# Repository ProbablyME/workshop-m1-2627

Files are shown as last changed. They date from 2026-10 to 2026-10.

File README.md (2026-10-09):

# Sentinel-X — Avant-poste industriel autonome (Groupe 1)

Prototype cyber-physique réalisé pour le Workshop EPSI M1 2026-27 « Mission Sentinel-X »
(AetherCorp Industrial Solutions). Un boîtier ESP8266 équipé de capteurs environnementaux
et de présence remonte ses données en MQTT chiffré vers un **PC Serveur Local** (option B :
laptop d'un apprenant) qui héberge la stack Docker, l'API, le dashboard de supervision et
l'IA de vision sur webcam USB.

## Architecture (option B)

```
                 Wi-Fi (sous-réseau de table 192.168.10.0/24)
                 (cible ; en démo, repli possible sur un hotspot partagé : seul MQTT_HOST change dans secrets.h)
┌────────────────────┐   MQTTS 8883 (TLS)   ┌──────────────────────────────────────────┐
│  Boîtier SENTINEL-X│ ───────────────────► │  PC Serveur Local (laptop)               │
│  ESP8266 NodeMCU   │ ◄─────────────────── │  ┌────────────┐  ┌──────┐  ┌──────────┐  │
│  DHT22 · MQ-2 · PIR│   sentinel/g1/cmd    │  │ Mosquitto  │─►│ API  │─►│ Postgres │  │
│  OLED · Buzzer · LED│                     │  └────────────┘  │FastAPI│ └──────────┘  │
└────────────────────┘                      │        ▲         └──┬───┘               │
                                            │        │            │ WebSocket + REST   │
                      Webcam USB ──────────►│  ┌─────┴─────┐  ┌───▼──────────────┐     │
                                            │  │ IA vision │  │ Dashboard React  │     │
                                            │  │ + prédictif│  │ (supervision)    │     │
                                            │  └───────────┘  └──────────────────┘     │
                                            └──────────────────────────────────────────┘
```

Détails : [docs/ARCHITECTURE.md](docs/ARCHITECTURE.md). Interfaces entre blocs :
[docs/CONTRAT_DONNEES.md](docs/CONTRAT_DONNEES.md) (référence unique pour les 4 filières).
Montage électronique : [docs/CABLAGE.md](docs/CABLAGE.md). Boîtier et Fablab : [docs/BOITIER.md](docs/BOITIER.md).
Base de données (schéma, console SQL, requêtes) : [docs/BASE_DE_DONNEES.md](docs/BASE_DE_DONNEES.md).

## Structure du dépôt

| Dossier | Filière | Contenu | État |
|---|---|---|---|
| `firmware/`  | DEV | Firmware ESP8266 C++ (PlatformIO / CLion) : capteurs, OLED, MQTTS, commandes | **fait** |
| `backend/` | DEV | API FastAPI : MQTT ↔ PostgreSQL ↔ WebSocket, `POST /api/v1/alerts` | **fait** |
| `dashboard/` | DEV | Interface React (tuiles, courbes temps réel, alertes, commandes, IA) | **fait** |
| `ai/` | IA | Vision YOLOv8n (intrusion + flux vidéo) et maintenance prédictive Isolation Forest | **fait** |
| `infra/` | INFRA | Config Mosquitto (TLS), scripts certificats / mots de passe / bootstrap | **fait** |
| `docs/` | tous | Contrat de données, architecture, câblage, boîtier, matrice de sécurité, rapport d'audit | en cours |
| `fablab/` | tous | Plaque de gravure laser (SVG), exports Fusion360 à venir | en cours |

## Démarrage rapide (PC Serveur Local)

Prérequis : Docker Desktop (ou Docker Engine + Compose v2), OpenSSL, Python 3.12+.

```bash
# 1. Génère .env (secrets aléatoires), la CA + le certificat MQTTS, le fichier de mots de passe
./infra/scripts/bootstrap.sh 192.168.10.1        # ← IP du laptop sur le réseau de table

# 2. Construit et lance Mosquitto + PostgreSQL + API
docker compose up -d --build

# 3. Vérifie
curl http://localhost:8000/api/v1/health
# → {"status":"ok","mqtt_connected":true,"db_ok":true,"ws_clients":0,"version":"0.1.0"}
```

Documentation interactive de l'API : http://localhost:8000/docs
Dashboard de supervision : http://localhost:8080 (utilisateur et mot de passe `DASHBOARD_*` du `.env`).

Si le port 8000 est déjà pris sur la machine, définir `API_PORT=8010` (ou autre) dans `.env`.

## Tester sans le boîtier physique

Un simulateur publie de la télémétrie et des alertes réalistes sur le broker :

```bash
python3 -m venv backend/.venv && backend/.venv/bin/pip install -r backend/requirements.txt
backend/.venv/bin/python backend/tools/simulate_esp.py --period 2 --intrusion      # MQTT 1883
backend/.venv/bin/python backend/tools/simulate_esp.py --tls --drift               # MQTTS 8883, dérive lente temp+gaz
```

Puis :

```bash
curl http://localhost:8000/api/v1/telemetry/latest
curl -X POST http://localhost:8000/api/v1/commands \
     -H "X-API-Key: $API_KEY" -H 'Content-Type: application/json' \
     -d '{"actuator":"buzzer","action":"pulse","duration_ms":1500}'
```

## Lancer l'IA (hors Docker, sur le laptop serveur)

```bash
cd ai && /opt/homebrew/bin/python3.12 -m venv .venv && .venv/bin/pip install -r requirements.txt
.venv/bin/python vision.py          # webcam → YOLOv8n, alerte intrusion, flux http://localhost:8001/stream
.venv/bin/python predict.py         # Isolation Forest sur la télémétrie, score toutes les 30 s
```

Détails dans [ai/README.md](ai/README.md).

## Développer le dashboard (hors Docker)

```bash
cd dashboard
npm install
npm run dev          # http://localhost:5173, proxifie /api et /ws vers l'API du .env (API_PORT)
npm run build        # build de production dans dist/, servi par nginx dans Docker
```

Le serveur Vite et nginx injectent tous deux l'en-tête `X-API-Key` côté serveur : la clé
n'apparaît jamais dans le code livré au navigateur. `?theme=dark` ou `?theme=light` dans l'URL
force le thème (utile pour l'écran du jury).

## Lancer l'API hors Docker (dev)

```bash
cd backend
DATABASE_URL=sqlite:///./sentinel-dev.db MQTT_HOST=localhost API_KEY=dev \
  .venv/bin/uvicorn app.main:app --reload --port 8000
```

Sans broker joignable, l'API démarre quand même (health en `degraded`) et les routes HTTP
restent utilisables, ce qui suffit pour développer le dashboard.

## Endpoints principaux

| Méthode | Route | Rôle |
|---|---|---|
| GET | `/api/v1/health` | état API / broker / base |
| POST | `/api/v1/alerts` | **endpoint obligatoire du sujet** |
| GET | `/api/v1/alerts` | historique des alertes |
| GET | `/api/v1/telemetry/latest` | dernière mesure |
| GET | `/api/v1/telemetry?minutes=30`  | série temporelle |
| POST | `/api/v1/commands` | pilote buzzer / LED via MQTT |
| GET | `/api/v1/devices` | état du boîtier (online, IP, firmware) |
| POST | `/api/v1/ai/detections` | détections de la vision IA |
| POST | `/api/v1/ai/predictions` | scores d'anomalie du modèle prédictif |
| WS | `/ws` | flux temps réel pour le dashboard |

Les écritures exigent l'en-tête `X-API-Key` (valeur `API_KEY` du `.env`).

## Sécurité

- **Aucun secret dans le dépôt** : `.env`, `infra/mosquitto/passwd`, `infra/mosquitto/certs/`
  et `firmware/include/secrets.h` sont ignorés par Git. Les secrets sont générés par `bootstrap.sh`.
- **MQTTS** : listener 8883 avec CA locale ; l'ESP8266 vérifie le serveur (CA ou empreinte SHA-1
  affichée par `gen-certs.sh`). Authentification login/mot de passe obligatoire (`allow_anonymous false`).
- Le listener 1883 en clair ne sert qu'au debug sur la table ; le fermer (UFW) avant le pentest.
- PostgreSQL n'expose aucun port sur l'hôte. L'API tourne sans privilège root dans son conteneur.
- Limites Mosquitto (`max_connections`, `max_queued_messages`, `max_packet_size`) contre le flood.
- Mosquitto avertit que `passwd` est lisible par tous (`644`) : nécessaire pour que le conteneur
  (uid 1883) le lise via le bind mount ; le fichier est hors Git.
- Hardening de l'hôte (UFW, SSH par clés, Docker) : voir `docs/` (à compléter jeudi).

## Jour de démo : maintien en condition opérationnelle

- Empêcher la veille du laptop serveur pendant la démo : `caffeinate -dims` dans un terminal, ou
  Réglages Système → Batterie → ne jamais mettre en veille sur secteur. Constaté le 5 octobre :
  98 minutes sans télémétrie pendant une veille du Mac, le boîtier s'est reconnecté seul au réveil.
- Laptop sur secteur, Wi-Fi de table en 2,4 GHz, `docker compose ps` tout en `healthy` avant de passer.
- Surveiller `heap_free` dans la télémétrie : ≈ 17,6 Ko après la session TLS, alerter sous 10 Ko.

## Équipe & conventions

- Groupe 1 — livrables nommés `Workshop2026-M1-G1-*`.
- Membres : Leo PIRONTI, Khalid FILALI, Ethan BREUZARD, Antoine LACHAUX, Lucas MATTERA, Cyprien BROCHE.
- Commits sémantiques : `feat(firmware): …`, `fix(api): …`, `docs: …`, `infra: …`.
- Toute modification d'interface passe d'abord par `docs/CONTRAT_DONNEES.md`.

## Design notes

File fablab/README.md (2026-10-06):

# Fablab : fichiers pour la découpe/gravure laser et l'impression 3D

| Fichier | Machine | Contenu |
|---|---|---|
| `plaque-gravure.svg` | Falcon A1 (laser)  | plaque 80 × 50 mm : logo AetherCorp, SENTINEL-X, S/N, sécurité |
| `boitier.py` → `export/*.step`, `*.stl` | K2 Plus (3D) | boîtier paramétrique généré par CadQuery : base, couvercle, gabarit de face ; STEP à importer dans Fusion 360 pour la finition |

Conventions du SVG : **noir** = gravure, **rouge** (trait 0,1 mm) = découpe. Dans LightBurn,
chaque couleur devient un calque avec ses propres vitesse/puissance. Convertir les textes en
chemins dans Inkscape (Chemin → Objet en chemin) si la police manque sur le poste laser.

Spécifications complètes du boîtier : [docs/BOITIER.md](../docs/BOITIER.md).

## Boîtier 3D : génération et import dans Fusion 360

```bash
cd fablab
/opt/homebrew/bin/python3.12 -m venv .venv && .venv/bin/pip install cadquery   # une fois (≈ 1,4 Go)
.venv/bin/python boitier.py                       # cotes par défaut
.venv/bin/python boitier.py --pack 118 62 --holes 108 52   # pack myDiL mesuré au pied à coulisse
```

Les cotes (parois 1,2 mm, positions des découpes, entraxe du pack, logement de la plaque) sont dans la
section PARAMÈTRES de `boitier.py`. Dans Fusion 360 : *Insérer → Insérer un fichier CAO* sur chaque
`.step` ; les corps sont modifiables (chanfreins, logos, ajustements). Imprimer d'abord
`gabarit-face.stl` (15 min) pour vérifier les découpes sur les vrais composants, puis `base.stl`
(ouverture vers le haut, sans support) et `couvercle.stl` (à plat, logement de la plaque vers le haut).

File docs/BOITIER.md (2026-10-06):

# Boîtier SENTINEL-X : spécifications pour la CAO (Fusion360) et le Fablab

Consignes du sujet : modélisation sur **Fusion360 exclusivement**, impression sur Creality K2 Plus,
cloisons **1,2 mm maximum**, électronique encapsulée proprement, **écran OLED visible**,
passe-câbles propres **sans fil apparent**, plaque gravée au laser (logo AetherCorp, consignes
de sécurité, numéro de série). L'impression 3D est longue : lancer la base dès lundi soir.

## 1. Ce qu'il y a à loger (mesurer au pied à coulisse lundi, valeurs indicatives)

| Élément | Encombrement (L × l × h) | Contrainte de montage |
|---|---|---|
| Pack myDiL (ESP + 2 breadboards) | **à mesurer**, ≈ 115 × 60 × 22 mm | 4 oreilles de fixation : relever l'entraxe des trous, ne pas désassembler |
| OLED 0.96" I2C | PCB 27 × 27 mm, 4 trous Ø2 (entraxe ≈ 23,5 mm) | zone d'affichage 22 × 11 mm décalée vers le haut du PCB |
| PIR HC-SR501 | PCB 32 × 24 mm, dôme Ø 23 mm, h ≈ 25 mm | trou Ø 23,5 mm en face avant, dôme en saillie, potentiomètres accessibles |
| MQ-2 (module) | PCB 32 × 20 mm, capsule Ø 16 mm, h ≈ 22 mm | grille d'aération obligatoire, chauffe (≈ 50 °C) |
| DHT22 (module) | 38 × 20 × 8 mm | fentes d'aération, loin du MQ-2 pour ne pas fausser la température |
| Buzzer actif | Ø 12 mm, h 9 mm | grille de 5 à 7 trous Ø 2 mm devant |
| LED bicolore 5 mm | Ø 5 mm | trou Ø 5,2 mm, collée ou support LED |
| Convertisseur DC-DC | ≈ 43 × 21 × 12 mm | production uniquement |
| 2 Wago + arrivée 7,5 V | ≈ 20 × 13 × 8 mm chacun | passe-câble Ø 6 mm ou presse-étoupe |
| Micro-USB de l'ESP | ouverture 12 × 8 mm | alignée sur le port, accessible sans ouvrir le boîtier |

## 2. Architecture proposée : 3 pièces

Modèle généré par `fablab/boitier.py` (CadQuery → STEP/STL, voir `fablab/README.md`), à importer et finaliser dans Fusion 360.

1. **Base** (le plus long à imprimer, à lancer en premier) : bac avec 4 plots à vis pour le pack
   myDiL, logements DC-DC et Wago, ouverture micro-USB latérale, passe-câble d'alimentation,
   pieds et chanfreins 45° pour imprimer sans support.
2. **Face avant** (pièce fine, rapide) : fenêtre OLED avec 4 plots, trou PIR, trou LED, grille
   buzzer, grille MQ-2, fentes DHT22, et l'emplacement en retrait pour la plaque gravée.
3. **Couvercle** : fermeture par 4 vis M3 (inserts chauffants ou trous Ø 2,8 mm pour vis
   autotaraudeuses), aérations latérales.

Dimensions intérieures cibles : ≈ 140 × 95 × 55 mm. À ajuster après mesure du pack.

## 3. Paramètres Fusion360 (User Parameters, pour tout ajuster en 30 secondes)

| Paramètre | Valeur | Commentaire |
|---|---|---|
| `wall` | 1,2 mm | consigne myDiL, = 3 lignes de buse 0,4 mm |
| `clear` | 0,3 mm | jeu entre pièces imprimées |
| `inner_L` | 140 mm | longueur intérieure |
| `inner_W` | 95 mm  | largeur intérieure |
| `inner_H` | 55 mm  | hauteur intérieure |
| `screw` | 2,8 mm | trou vis M3 autotaraudeuse |
| `pir_hole` | 23,5 mm| dôme PIR |
| `led_hole` | 5,2 mm | LED 5 mm |
| `oled_win_W` | 24 mm  | fenêtre écran (zone active 22 mm + jeu) |
| `oled_win_H` | 13 mm  | |
| `plate_L` | 80 mm  | plaque gravée laser |
| `plate_W` | 50 mm  | |
| `plate_T` | 3 mm | plexi ou bois 3 mm |

## 4. Réglages d'impression (Creality Print / K2 Plus)

- Matière PLA, buse 0,4 mm, couches 0,2 mm, parois 3 lignes (1,2 mm), remplissage 15 % gyroïde.
- Pas de support : toutes les ouvertures latérales en forme de « pont » ≤ 10 mm ou avec chanfrein 45° en haut.
- Orienter la face avant à plat, fenêtre vers le haut. Base ouverture vers le haut.
- Temps estimé : base ≈ 4 à 5 h, face avant ≈ 1 h, couvercle ≈ 2 h. Lancer la base lundi soir.
- Première impression : un **gabarit de test** 2 mm d'épaisseur avec juste les découpes (OLED, PIR, LED) pour vérifier les cotes en 15 minutes avant d'imprimer la vraie face.

## 5. Gravure et découpe laser (Falcon A1)

- Support : plexi 3 mm (rendu « produit fini ») ou contreplaqué 3 mm (plus rapide).
- Fichier : `fablab/plaque-gravure.svg`, 80 × 50 mm. Noir = gravure, rouge = découpe.
- Contenu : logo AetherCorp, « SENTINEL-X · Edge Node », S/N `SX-G1-01`, pictogrammes de sécurité
  (tension 7,5 V, ne pas ouvrir sous tension, surface chaude côté MQ-2), « Groupe 1 · EPSI 2026 ».
- Dans LightBurn ou Falcon Design Space : importer le SVG, assigner gravure au calque noir
  (vitesse haute, puissance basse) et découpe au calque rouge (vitesse basse, 2 passes sur plexi).
- Fixation : 4 trous Ø 3,2 mm aux coins (vis M3) ou double-face, dans le retrait prévu en face avant.
- Bonus rapide : une seconde petite plaque 40 × 15 mm « AetherCorp » à coller sur le couvercle.

## 6. Checklist Fablab (à cocher)

- [ ] Lundi : mesures du pack, des modules et de l'entraxe des trous. Esquisse Fusion360 avec les paramètres ci-dessus.
- [ ] Lundi soir : impression du gabarit de test puis de la base.
- [ ] Mardi : face avant et couvercle. Export SVG final de la plaque, test de gravure sur chute.
- [ ] Mercredi : montage électronique dans le boîtier, gestion des câbles (colliers, chemins de câbles imprimés), tournage B-Roll.
- [ ] Jeudi matin (gel du code) : finitions, plaque collée, étiquette S/N sous le boîtier, photos pour le dossier.

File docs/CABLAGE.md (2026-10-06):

# Câblage du boîtier SENTINEL-X (Groupe 1)

Carte : **NodeMCU Lolin v3 (ESP8266 ESP-12E)**, montée sur le pack myDiL avec 2 breadboards
170 points. **Ne pas désassembler le pack.** Toutes les entrées/sorties de l'ESP sont en **3,3 V**.

## 0. Montage minimal (celui qu'on fait)

Tout sur l'USB, sans transistor ni pont diviseur ni bloc 7,5 V. Suffisant pour la démo.

| Composant | Branchement |
|---|---|
| OLED | SCL → D1, SDA → D2, VCC → 3V, GND → G |
| DHT22 | DATA → D5, VCC → 3V, GND → G |
| PIR | OUT → D6, VCC → VU (5 V USB), GND → G |
| MQ-2 | AO → A0, **VCC → 3V** (pas 5 V : sans diviseur, A0 reste sous 3,3 V), GND → G |
| LED | rouge → 220 Ω → D0, verte → 220 Ω → D8, cathode commune → G |
| Buzzer passif 3 broches | S (signal) → D7, VCC → VU (5 V, plus fort) ou 3V, GND → G. Broche du milieu sans nom : laisser libre. Le firmware joue une mélodie (thème Mario) par PWM |

Courses : 13 câbles mâle/femelle, 4 mâle/mâle, 2 résistances 220 Ω. C'est tout.
Le MQ-2 en 3,3 V est moins sensible mais réagit à un briquet non allumé ou à un coton d'alcool.
Mettre `MQ2_DIVIDER_RATIO 1.0f` et `MQ2_VCC 3.3f` dans `firmware/include/config.h`.
Les sections suivantes décrivent la version complète, optionnelle.

## 1. Brochage retenu

| Composant | Broche composant | Broche NodeMCU | GPIO | Remarque |
|---|---|---|---|---|
| OLED 0.96" I2C | SCL | **D1** | GPIO5  | bus I2C |
| OLED 0.96" I2C | SDA | **D2** | GPIO4  | bus I2C |
| OLED 0.96" I2C | VCC / GND | 3V / G | | adresse 0x3C |
| DHT22 (module 3 pins)| DATA | **D5** | GPIO14 | le module intègre la résistance de pull-up |
| DHT22 | VCC / GND | 3V / G | | fonctionne en 3,3 V |
| PIR HC-SR501 | OUT | **D6** | GPIO12 | sortie 3,3 V, sans danger pour l'ESP |
| PIR HC-SR501 | VCC / GND | **5V** / G | | régulateur embarqué, alimenter en 5 V |
| MQ-2 | AO | **A0** | ADC | **via pont diviseur** 10 kΩ / 20 kΩ (voir §3) |
| MQ-2 | DO | non câblé | | sortie 5 V, interdite sur l'ESP |
| MQ-2 | VCC / GND | **5V** / G | | résistance chauffante ~150 mA |
| Buzzer actif 3 V | + | **D7** | GPIO13 | via transistor NPN (§3), ou direct pour tester |
| LED bicolore | anode ROUGE | **D0** | GPIO16 | résistance 220 Ω en série |
| LED bicolore | anode VERTE | **D8** | GPIO15 | résistance 220 Ω en série |
| LED bicolore | cathode commune  | G | | |

Pourquoi ces broches : **D3 (GPIO0), D4 (GPIO2)** doivent être à l'état haut au démarrage et
**D8 (GPIO15)** à l'état bas, sinon l'ESP part en mode flash ou ne boote pas. Une LED vers la
masse sur D8 respecte cette règle ; une LED sur D3 ou D4 l'enfreint. D0 n'a pas de PWM ni
d'interruption, ce qui est sans importance pour une LED.

Le **5V** est la broche **VU** (« VOUT USB ») de la Lolin v3 en phase développement, ou le
rail 5 V du convertisseur DC-DC en phase production (§4).

## 2. Liste de courses au myDiL

### Câbles Dupont

| Type | Quantité | Usage |
|---|---|---|
| **Mâle / Femelle** | **15** | modules à connecteurs mâles vers breadboard : OLED 4, DHT22 3, PIR 3, MQ-2 3, + 2 de réserve |
| **Mâle / Mâle** | **10** | ponts sur breadboard : rails 3,3 V / 5 V / masse, diviseur, transistor, LED |
| USB-A vers micro-USB 1 m | 1  | fourni, flash + alimentation en développement |

Prendre des câbles **courts (10 cm)** pour l'intérieur du boîtier, sauf 3 de 20 cm pour le PIR
qui sera sur la face avant.

### Composants passifs et actifs

| Composant | Quantité | Usage |
|---|---|---|
| Résistance 220 Ω (ou 330 Ω)  | 2 | protection LED rouge / verte |
| Résistance 10 kΩ | 1 | diviseur MQ-2 (haut) |
| Résistance 20 kΩ (ou 2×10 kΩ en série) | 1 | diviseur MQ-2 (bas) |
| Transistor NPN (2N2222, S8050, BC547) | 1 | commande buzzer |
| Résistance 1 kΩ | 1 | base du transistor |
| Bloc 220 V → 7,5 V + 2 Wago  | 1 | alimentation phase production |
| Convertisseur DC-DC 7,5 V → 5 V | 1 | rail 5 V pour PIR + MQ-2 en production |

Si le myDiL n'a pas de transistor, le buzzer actif 3 V peut se brancher directement D7 → buzzer+
et buzzer− → G pour les tests. Un GPIO ESP8266 délivre 12 mA : si le buzzer réclame plus, il
sonnera faiblement et l'ESP peut redémarrer. Le transistor est la solution propre.

## 3. Schémas des sous-ensembles

### Diviseur de tension MQ-2 → A0

La sortie AO du MQ-2 monte jusqu'à 5 V. L'entrée A0 de la NodeMCU accepte 0 à 3,3 V.

```
MQ-2 AO ───[ 10 kΩ ]───┬─── A0 (NodeMCU)
                       │
                    [ 20 kΩ ]
                       │
                      GND
```

V(A0) = V(AO) × 20 / 30, donc 5 V → 3,33 V. Le firmware multiplie par 1,5 (`MQ2_DIVIDER_RATIO`).

Alternative dégradée : alimenter le MQ-2 en 3,3 V sans diviseur. La sensibilité chute fortement,
à n'utiliser qu'en dépannage.

### Commande du buzzer par transistor NPN

```
D7 ───[ 1 kΩ ]─── Base
                  Collecteur ─── Buzzer (−)
                                 Buzzer (+) ─── 3V (ou 5V si buzzer 5 V)
                  Émetteur ───── GND
```

Le buzzer est actif (mono-ton) : un niveau haut sur D7 le fait sonner, pas besoin de PWM.

### LED bicolore à cathode commune

```
D0 ───[ 220 Ω ]─── anode ROUGE ─┐
D8 ───[ 220 Ω ]─── anode VERTE ─┤ LED
                   cathode ─────┴─── GND
```

Identifier les pattes : la plus longue est en général la cathode commune, à vérifier au multimètre
ou en testant avec 3V + résistance.

## 4. Alimentation : deux modes, jamais les deux en même temps

| Mode | ESP8266 | Rail 5 V (PIR, MQ-2) | Rail 3,3 V (OLED, DHT22) |
|---|---|---|---|
| **Développement** | câble USB depuis le PC | broche **VU** de la NodeMCU | broche **3V** |
| **Production (démo)**| bloc 7,5 V → DC-DC 5 V → **VIN** | sortie du DC-DC 5 V | broche **3V** |

Règle absolue du myDiL : **ne jamais brancher le bloc 7,5 V sur VIN pendant que le câble USB
est connecté.** Pour flasher en phase production, débrancher le bloc, brancher l'USB, flasher,
débrancher l'USB, rebrancher le bloc.

Pourquoi passer par le DC-DC avant VIN plutôt que 7,5 V direct sur VIN : le régulateur AMS1117
de la NodeMCU chauffe nettement sous 7,5 V, et le rail 5 V est de toute façon nécessaire pour le
PIR et le MQ-2. Une seule source 5 V alimente tout, c'est plus simple à câbler proprement dans le
boîtier. Le schéma du myDiL (7,5 V sur VIN + DC-DC séparé) fonctionne aussi.

Budget courant en 5 V : ESP ~80 mA (pics 300 mA Wi-Fi) + MQ-2 150 mA + PIR 65 mA + OLED 20 mA
+ buzzer 30 mA ≈ 350 mA, pics 600 mA. Le bloc 1 A et un port USB 500 mA conviennent (le MQ-2
peut être laissé débranché pendant le flash si le port USB est faible).

## 5. Ordre de montage conseillé (mardi matin)

1. ESP seul en USB, flasher le firmware, vérifier l'OLED (adresse 0x3C) : le plus simple à valider.
2. DHT22 sur D5 : vérifier température et humidité sur le moniteur série.
3. PIR sur D6 : régler les deux potentiomètres (sensibilité à mi-course, délai au minimum), cavalier en mode « H » (répétable).
4. LED + résistances, puis buzzer + transistor : tester avec `POST /commands`.
5. MQ-2 en dernier avec son diviseur, laisser chauffer 2 à 3 minutes avant de lire des valeurs stables.
6. Vérifier dans le dashboard que la télémétrie arrive, puis passer en MQTTS.

## 6. Pièges connus

- Le MQ-2 chauffe (normal) et consomme : le brancher en dernier, sur le 5 V, jamais sur le 3V de l'ESP pour l'OLED partagé.
- Le PIR met 30 à 60 s à se stabiliser après mise sous tension et déclenche à vide pendant ce temps.
- Le DHT22 ne se lit pas plus d'une fois toutes les 2 s.
- Lire A0 trop souvent perturbe le Wi-Fi : le firmware le lit toutes les 2 s, ne pas descendre en dessous.
- Un reset en boucle avec le message `rst cause:4` ou `wdt reset` signale une alimentation faible ou un GPIO de boot mal tiré (D3/D4/D8).
- **Port série qui disparaît sur macOS** (« Resource busy », « Device not configured ») : le pilote CH340 natif de macOS 14/15 détache la carte quand un programme force les lignes DTR/RTS à l'ouverture du port. Ce n'est pas un problème d'alimentation : un ESP seul tient très bien sur un hub USB. Utiliser `make monitor` (`pio device monitor`), qui ouvre le port correctement, et ne pas écrire de script série maison qui met DTR/RTS à 0 avant l'ouverture. Si le problème persiste, installer le pilote WCH CH34xVCPDriver.

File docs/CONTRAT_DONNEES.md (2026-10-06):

# Contrat de données Sentinel-X (Groupe 1)

Ce document est la référence unique pour les interfaces entre le boîtier
(ESP8266), le serveur (API Python), le dashboard (React) et les scripts IA.
Toute modification ici doit être répercutée dans le firmware, l'API et le dashboard.

## 1. Identifiants

| Élément | Valeur |
|---|---|
| Groupe | `g1` |
| Device ID | `SX-G1-01` |
| Préfixe topics | `sentinel/g1/` |

## 2. Topics MQTT

| Topic | Sens | QoS | Retain | Fréquence |
|---|---|-----|---|---|
| `sentinel/g1/telemetry`  | ESP → serveur | 0 | non | toutes les 5 s |
| `sentinel/g1/alerts` | ESP → serveur | 1 | non | sur changement d'état |
| `sentinel/g1/status` | ESP → serveur | 1 | oui | connexion + LWT |
| `sentinel/g1/cmd` | serveur → ESP | 1 | non | action superviseur |
| `sentinel/g1/ai` | IA → serveur  | 0 | non | sur détection (optionnel)  |

Le script IA peut aussi parler directement à l'API en HTTP (voir §4), ce qui
est le chemin recommandé.

## 3. Payloads JSON

Tous les timestamps sont en millisecondes depuis le boot de l'ESP (`uptime_ms`)
ou en ISO 8601 UTC côté serveur. Le serveur horodate à réception.

### 3.1 `sentinel/g1/telemetry`

```json
{
  "device_id": "SX-G1-01",
  "uptime_ms": 123456,
  "temperature": 23.4,
  "humidity": 45.2,
  "gas_raw": 312,
  "gas_ppm": 180.5,
  "motion": false,
  "rssi": -61,
  "heap_free": 32768
}
```

| Champ | Type | Unité / plage | Capteur |
|---|---|---|---|
| `temperature` | float  | °C, -40 à 80 | DHT22 |
| `humidity` | float  | %, 0 à 100 | DHT22 |
| `gas_raw` | int | 0 à 1023 (ADC A0) | MQ-2 |
| `gas_ppm` | float  | estimation ppm, 0 si non calibré | MQ-2 |
| `motion` | bool | présence détectée | PIR HC-SR501 |
| `rssi` | int | dBm | Wi-Fi |
| `heap_free` | int | octets | ESP8266 |

### 3.2 `sentinel/g1/alerts`

Émis par l'ESP quand un seuil local est franchi ou qu'un état change.
Les seuils locaux servent d'alerte « réflexe » ; l'IA prédictive est côté serveur.

```json
{
  "device_id": "SX-G1-01",
  "uptime_ms": 123456,
  "type": "motion",
  "state": "on",
  "value": 1,
  "severity": "warning"
}
```

| Champ | Valeurs |
|---|---|
| `type` | `motion`, `gas`, `temperature`, `humidity`, `sensor_fault` |
| `state` | `on` (début) ou `off` (fin) |
| `severity` | `info`, `warning`, `critical` |
| `value` | valeur mesurée ayant déclenché l'alerte |

### 3.3 `sentinel/g1/status` (retained + Last Will)

```json
{ "device_id": "SX-G1-01", "online": true, "ip": "192.168.10.50", "fw": "0.1.0" }
```

Le Last Will publié par le broker à la déconnexion : `{"device_id":"SX-G1-01","online":false}`.

### 3.4 `sentinel/g1/cmd` (serveur → ESP)

```json
{ "actuator": "buzzer", "action": "on", "duration_ms": 2000, "cmd_id": "c-42" }
```

| Champ | Valeurs |
|---|---|
| `actuator` | `buzzer`, `led_red`, `led_green`, `led`, `camera` (intrusion vue par l'IA : `on`/`off`, le boîtier affiche « ALERTE CAMERA », allume la LED rouge et bipe) |
| `action` | `on`, `off`, `blink`, `pulse` |
| `duration_ms` | optionnel, auto-extinction après N ms |
| `cmd_id` | identifiant de traçabilité, journalisé par l'ESP sur le port série |

Sémantique côté firmware : `on` sans durée reste manuel jusqu'à la prochaine commande ; `pulse` dure 1 s par défaut, `blink` 3 s ; **`off` rend la main au mode automatique** (LED verte = nominal, LED rouge = alerte ou liaison perdue) et coupe la sirène automatique. L'actionneur `led` applique l'action aux deux LED.

## 4. API REST (serveur, port 8000)

Base URL : `http://<ip-serveur>:8000/api/v1`

| Méthode | Route | Rôle |
|---|---|---|
| GET | `/health` | état API, broker, base |
| POST | `/alerts` | **endpoint obligatoire du sujet**, réception d'une alerte |
| GET | `/alerts?limit=50` | historique des alertes |
| GET | `/telemetry/latest` | dernière mesure |
| GET | `/telemetry?minutes=30`  | série temporelle récente |
| POST | `/commands` | envoie une commande à l'ESP (publie sur `/cmd`) |
| GET | `/commands?limit=20` | historique des commandes |
| GET | `/devices` | état des boîtiers (online, ip, last_seen) |
| POST | `/ai/detections` | le script vision pousse une détection |
| GET | `/ai/detections?limit=20`| historique des détections |
| POST | `/ai/predictions` | le modèle prédictif pousse un score d'anomalie |

Corps de `POST /alerts` : identique au payload §3.2, `device_id` obligatoire.
Corps de `POST /ai/detections` :

```json
{ "source": "yolo", "label": "person", "confidence": 0.87, "bbox": [120, 40, 300, 420], "frame_w": 640, "frame_h": 480 }
```

Corps de `POST /ai/predictions` :

```json
{ "model": "isolation_forest", "score": -0.21, "is_anomaly": true, "window_s": 300, "features": {"temp_slope": 0.12, "gas_slope": 3.4} }
```

Écriture protégée par l'en-tête `X-API-Key` (valeur dans `.env`, jamais commitée).

## 5. WebSocket (dashboard)

URL : `ws://<ip-serveur>:8000/ws`

Le serveur pousse des messages enveloppés :

```json
{ "kind": "telemetry" | "alert" | "status" | "command" | "detection" | "prediction", "ts": "2026-10-06T09:12:00Z", "data": { ... } }
```

Le dashboard ne publie rien sur le WebSocket ; les commandes passent par `POST /commands`.

## 6. Seuils locaux par défaut (firmware)

| Mesure | Warning | Critical |
|---|---|---|
| Température | > 35 °C | > 45 °C  |
| Humidité | > 80 %  | > 90 % |
| Gaz (raw) | ligne de base + 80 | ligne de base + 200 |

La ligne de base du gaz est mesurée par le boîtier après 3 min de chauffe du MQ-2 et suit la dérive lente du capteur. Ces seuils sont des garde-fous physiques. La détection fine (corrélation lente
température + gaz) est faite par l'IA côté serveur, conformément au sujet.

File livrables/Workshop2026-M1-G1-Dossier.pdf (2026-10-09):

SENTINEL-X · Consortium Groupe 1 · Dossier d'ingénierie technique | Page 1 / 16

WORKSHOP NATIONAL BAC+4 · SPRINT D'INGÉNIERIE · OCTOBRE 2026

# SENTINEL-X

## Dossier d'ingénierie technique — L'avant-poste industriel du futur

AetherCorp Industrial Solutions · Prototype cyber-physique de surveillance autonome

Consortium
Groupe 1 — EPSI Montpellier

Variante d'architecture
Option B : PC Serveur Local = ordinateur portable d'un apprenant Membres
Leo PIRONTI, Khalid FILALI, Ethan BREUZARD, Antoine LACHAUX, Lucas MATTERA, Cyprien BROCHE

Version
1.1 — vendredi 9 octobre 2026 · rapport d'audit (section 10) en cours d'intégration
Dépôt de code
Workshop2026-M1-G1-Code.zip — README exhaustif, aucun secret en clair

Livrables associés
Workshop2026-M1-G1-Pres.pptx · Workshop2026-M1-G1-VidDrop.mp4

SENTINEL-X · Consortium Groupe 1 · Dossier d'ingénierie technique | Page 2 / 16

# 0 Sommaire

1. Contexte, périmètre et état du prototype
2. Architecture générale
3. Réseau : topologie et plan d'adressage
4. Électronique : composants et schéma de câblage
5. Firmware ESP8266
6. Serveur : conteneurs, API, base de données
7. Dashboard de supervision
8. Intelligence artificielle locale
9. Sécurité : matrice, chiffrement, durcissement
10. Rapport d'audit post-pentest
11. Exploitation et maintien en condition opérationnelle
12. Fabrication numérique (Fablab)
13. Annexe — Index du dépôt

Le poster A3 (paysage) est inséré en dernière page du document.

SENTINEL-X · Consortium Groupe 1 · Dossier d'ingénierie technique | Page 3 / 16

# 1 Contexte, périmètre et état du prototype

AetherCorp déploie des micro-centrales isolées exposées à trois menaces simultanées : cyberattaques, intrusions physiques et risques environnementaux (fuites de gaz, surchauffes). SENTINEL-X est un boîtier de surveillance autonome (Edge Node) relié sans fil et de manière chiffrée à un Centre de Commandement Tactique matérialisé par le PC Serveur Local.

Le consortium a retenu l'option B : aucun Raspberry Pi, le serveur est l'ordinateur portable d'un apprenant qui héberge la pile Docker, l'API, le dashboard et les deux scripts d'intelligence artificielle, la webcam USB étant branchée directement dessus.

## 1.1 Les quatre piliers du sujet et leur couverture

Pilier | Exigence du cahier des charges | État
Edge Computing & IoT | Firmware C++ unique sur ESP8266, lecture cadencée des capteurs, OLED I2C, payloads structurés, actionneurs pilotables à distance | Réalisé et validé sur matériel
IA locale | Détection de présence humaine en temps réel sur webcam (< 100 ms / trame) ; maintenance prédictive sur séries temporelles sans simples conditions statiques | Réalisé (33–45 ms / trame, Isolation Forest)
Infrastructure & centralisation | Stack conteneurisée Docker Compose (base, API, broker MQTT), point d'accès Wi-Fi de table, plan d'adressage isolé | Stack réalisée · AP de table à déployer mardi
Cybersécurité | TLS de bout en bout ESP → serveur, durcissement du serveur, audit offensif croisé jeudi | MQTTS réalisé · durcissement hôte et audit jeudi

## 1.2 Chiffres clés mesurés

## 1.3 Ce qui a été produit

Firmware ESP8266 (C++/PlatformIO) : 3 capteurs, OLED, buzzer mélodique, LED bicolore, MQTTS, commandes, mode banc d'essai. Serveur : Mosquitto (TLS), PostgreSQL, API FastAPI (REST + WebSocket), nginx, scripts de bootstrap, certificats, base.
Dashboard React : indicateurs, courbes temps réel, journal d'alertes, panneau de commande, panneau IA avec flux vidéo.
IA : vision YOLOv8n sur webcam USB avec alerte d'intrusion ; maintenance prédictive par Isolation Forest.
Documentation : contrat de données, architecture, câblage, boîtier, base de données, ce dossier, plaque laser.

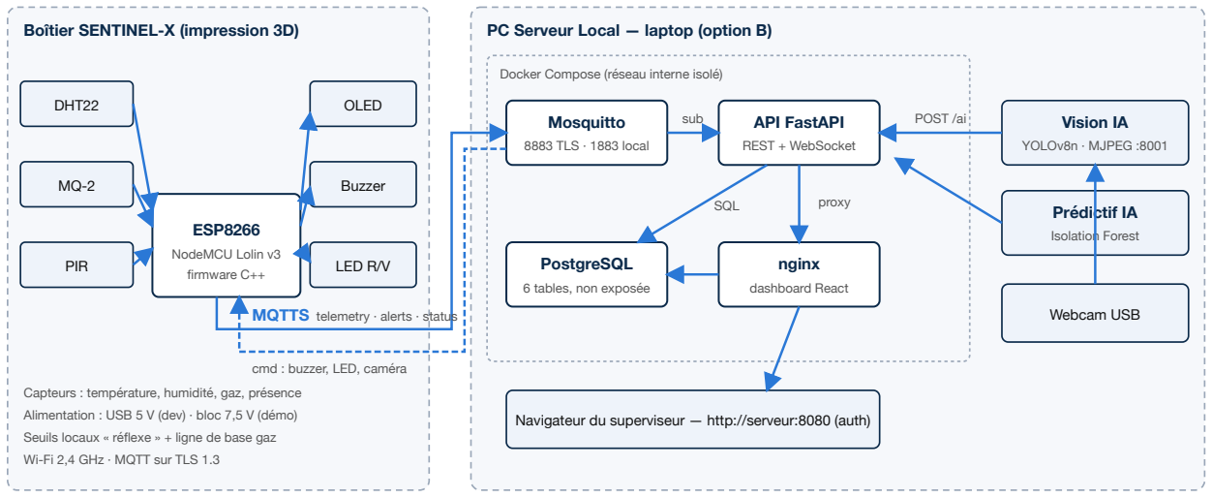
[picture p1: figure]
Boîtier SENTINEL-X (impression 3D); ESP8266; NodeMCU Lolin v3 firmware C++; DHT22; PIR; OLED; Buzzer; LED R/V; Wi-Fi 2,4 GHz · MQTT sur TLS 1.3; PC Serveur Local — laptop (option B); Docker Compose (réseau interne isolé); Mosquitto; 8883 TLS · 1883 local; API FastAPI; REST + WebSocket; PostgreSQL; 6 tables, non exposée; nginx; dashboard React; sub; SQL; proxy; Vision IA; YOLOv8n · MJPEG :8001; Prédictif IA; Isolation Forest; Webcam USB; POST /ai; MQTTS telemetry · alerts · status; cmd : buzzer, LED, caméra

SENTINEL-X · Consortium Groupe 1 · Dossier d'ingénierie technique | Page 4 / 16

# 2 Architecture générale

Capteurs : température, humidité, gaz, présence Alimentation : USB 5 V (dev) · bloc 7,5 V (démo) Seuils locaux « réflexe » + ligne de base gaz

Navigateur du superviseur — http://serveur:8080 (auth)

Figure 1 — Architecture logicielle et matérielle. Flèches pleines : flux de données ; pointillés : commandes descendantes.

## 2.1 Choix techniques et justification

Brique | Choix | Pourquoi
Transport boîtier → serveur | MQTT sur TLS (Mosquitto) | Léger pour un microcontrôleur, reconnexion et Last Will intégrés, un seul lien chiffré à maintenir, topics lisibles par toutes les filières.
API | Python / FastAPI | Asynchrone natif pour le WebSocket, validation stricte des payloads (Pydantic), documentation OpenAPI générée pour le jury.
Base de données | PostgreSQL 16 | Séries temporelles simples indexées sur l'horodatage, directement exploitables par Scikit-Learn ; 17 280 lignes/jour ≈ 2 Mo.
Dashboard | React + TypeScript, servi par nginx | Rendu temps réel par WebSocket ; nginx injecte la clé API côté serveur et protège l'accès par mot de passe.
Vision | YOLOv8n (Ultralytics) | Détection de personne robuste, 33 ms par trame sur CPU Apple M4 en 640×480, modèle de 6 Mo.
Prédictif | Isolation Forest (Scikit-Learn) | Non supervisé : pas d'incident étiqueté nécessaire ; détecte une fenêtre « anormale » par sa forme (pentes, variabilité, corrélation).
Montage électronique | Version minimale sur USB | Six composants obligatoires sans transistor ni pont diviseur, MQ-2 en 3,3 V : moins de points de panne pour la démo.

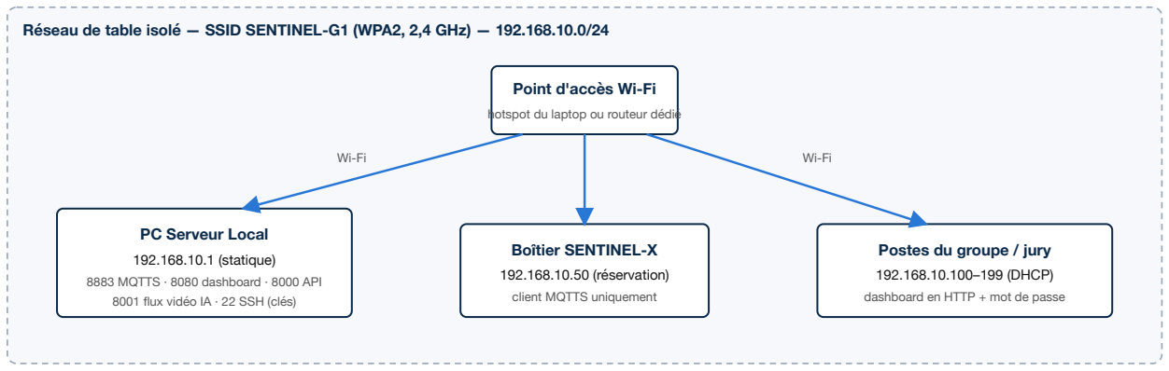
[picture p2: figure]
Point d'accès Wi-Fi; hotspot du laptop ou routeur dédié; PC Serveur Local; 192.168.10.1 (statique); 8883 MQTTS · 8080 dashboard · 8000 API 8001 flux vidéo IA · 22 SSH (clés); Boîtier SENTINEL-X; 192.168.10.50 (réservation); client MQTTS uniquement; Postes du groupe / jury; 192.168.10.100–199 (DHCP); dashboard en HTTP + mot de passe

SENTINEL-X · Consortium Groupe 1 · Dossier d'ingénierie technique | Page 5 / 16

# 3 Réseau : topologie et plan d'adressage

Réseau de table isolé — SSID SENTINEL-G1 (WPA2, 2,4 GHz) — 192.168.10.0/24

Figure 2 — Topologie du réseau de table. Aucun routage vers les autres tables ; seul le serveur dispose éventuellement d'un accès Internet.

Port | Service | Exposé à | Protection
8883 | MQTTS (Mosquitto) | boîtier, scripts IA | TLS 1.3, login/mot de passe, anonyme refusé, limites anti-flood
1883 | MQTT en clair | localhost uniquement (debug) | à fermer au pare-feu avant le pentest
8000 (8010 en dev) | API REST + WebSocket | postes du groupe | clé API sur toutes les écritures, validation des payloads, CORS restreint
8080 | Dashboard (nginx) | postes du groupe, jury | authentification HTTP, en-têtes de durcissement, clé API jamais côté navigateur
8001 | Flux vidéo MJPEG de l'IA | navigateur du superviseur | lecture seule, à restreindre au laptop pour la démo
5432 | PostgreSQL | personne (réseau Docker interne) | pas de port publié sur l'hôte

Au test de bout en bout du 5 octobre, le boîtier a rejoint le réseau en 2 s, établi la session TLS avec le serveur et maintenu un signal de −46 dBm. Après une mise en veille du serveur de 98 minutes, il s'est reconnecté seul sans intervention : le Last Will MQTT a marqué le boîtier hors ligne, puis en ligne au retour.

Le réseau de table isolé ci-dessus est la cible. Faute de routeur dédié disponible pendant le sprint, la démonstration tourne sur un hotspot Wi-Fi partagé avec les autres groupes : le serveur reçoit son IP par DHCP et l'épinglage du certificat sur le boîtier reste valide car il porte sur l'empreinte, pas sur l'adresse. Ce repli renforce même la démonstration : le lien boîtier → serveur est chiffré de bout en bout alors même que d'autres tables partagent le même segment. L'isolation réseau reste un point de durcissement (§ 9.3).

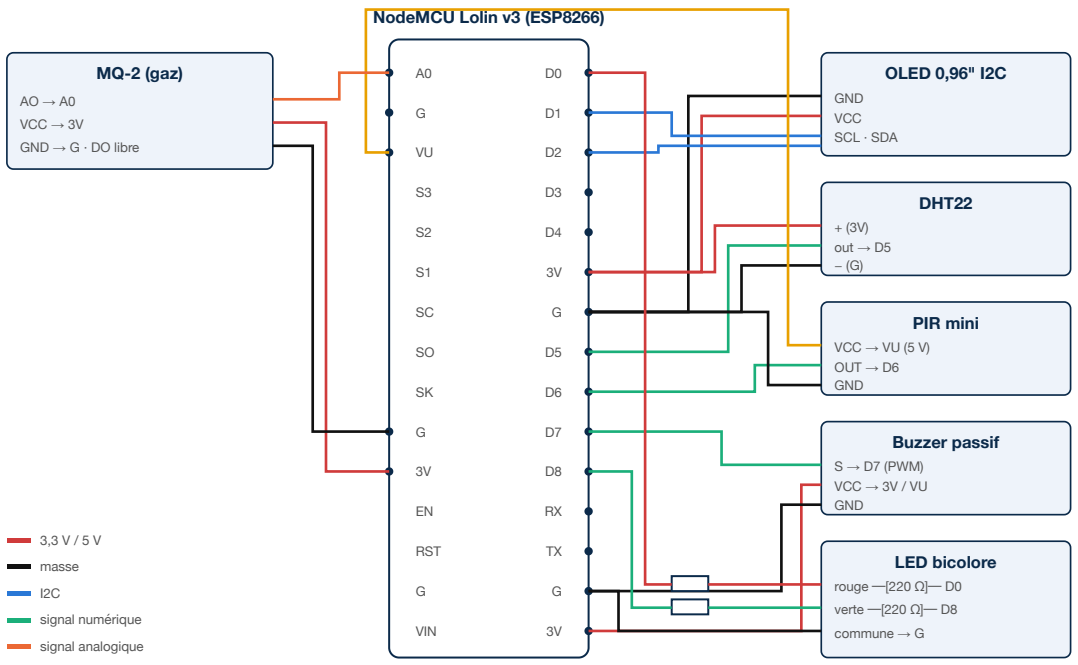
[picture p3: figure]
NodeMCU Lolin v3 (ESP8266); RST; VIN; OLED 0,96" I2C; GND VCC SCL · SDA; DHT22; + (3V) out → D5 − (G); PIR mini; VCC → VU (5 V) OUT → D6 GND; Buzzer passif; S → D7 (PWM) VCC → 3V / VU GND; LED bicolore; rouge ─[220 Ω]─ D0; verte ─[220 Ω]─ D8; commune → G; MQ-2 (gaz); VCC → 3V; GND → G · DO libre; masse; signal numérique; signal analogique

SENTINEL-X · Consortium Groupe 1 · Dossier d'ingénierie technique | Page 6 / 16

# 4 Électronique : composants et schéma de câblage

Composant | Rôle | Alimentation | Broche ESP | Remarque
ESP8266 NodeMCU Lolin v3 | microcontrôleur, Wi-Fi, firmware | USB 5 V (dev) / 7,5 V sur VIN (démo) | — | monté sur le pack myDiL, 2 breadboards 170 pts
OLED 0,96" I2C (0x3C) | IP, état Wi-Fi/MQTT, mesures, alertes | 3,3 V | D1 SCL · D2 SDA | visible en face avant
DHT22 (module 3 broches) | température et humidité | 3,3 V | D5 | résistance de rappel intégrée au module
MQ-2 | gaz combustibles / fumée | 3,3 V volontairement | A0 (analogique) | pas de pont diviseur ; seuils relatifs à la ligne de base
PIR mini (APKLVSR) | présence | 5 V (VU) | D6 | sortie 3,3 V, sans potentiomètre, délai fixe
Buzzer passif (module 3 broches) | alarme mélodique par PWM | 3,3 V ou 5 V (VU) | D7 | mélodie extraite des données de jeu Doom (E1M1)
LED bicolore cathode commune | vert = nominal, rouge = alerte / liaison perdue | — | D0 rouge · D8 verte | 2 × 220 Ω

Broches de démarrage préservées : D3 (GPIO0), D4 (GPIO2) et D8 (GPIO15) ne reçoivent qu'une LED vers la masse (D8), jamais de signal au niveau haut au boot. D3/D4/EN/RST/VIN restent libres : un fil mal placé sur EN a figé la carte lors du premier câblage, l'erreur est documentée dans le guide.

Figure 3 — Schéma de câblage du montage minimal, entièrement alimenté par l'USB en développement.

## 4.1 Alimentation et courant

Deux modes exclusifs : en développement, l'ESP est alimenté par le câble USB et fournit le 3,3 V (broche 3V) et le 5 V de l'USB (broche VU) ; en démonstration, le bloc 220 V → 7,5 V alimente VIN, et le convertisseur DC-DC 7,5 V → 5 V fournit le rail 5 V. Le bloc 7,5 V n'est jamais branché en même temps que l'USB. Budget mesuré en 5 V : ESP ≈ 80 mA (pics 300 mA au démarrage radio), MQ-2 ≈ 150 mA, PIR ≈ 65 mA, OLED ≈ 20 mA, soit ≈ 350 mA en régime établi. Le firmware désactive la calibration radio au boot et limite la puissance d'émission à 17 dBm pour réduire les pics sur une alimentation USB.

SENTINEL-X · Consortium Groupe 1 · Dossier d'ingénierie technique | Page 7 / 16

# 5 Firmware ESP8266

Un seul fichier firmware/src/main.cpp (C++, framework Arduino, PlatformIO, carte esp12e ), boucle non bloquante cadencée par millis() . Compilation : 31 Ko de RAM statique (38 %), 424 Ko de flash (41 %), ≈ 17,6 Ko de tas libre une fois la session TLS établie.

Événement | Comportement
Toutes les 2 s | lecture DHT22 (filtre de plausibilité −40…80 °C, 0…100 %), médiane de 8 échantillons ADC du MQ-2, état PIR
Toutes les 5 s | publication sentinel/g1/telemetry (température, humidité, gaz brut et ppm estimés, présence, RSSI, tas libre)
Franchissement de seuil | publication sentinel/g1/alerts à l'entrée, à l'escalade (attention → critique) et à la sortie avec hystérésis
Gaz | 3 min de chauffe sans alerte, ligne de base = moyenne sur 20 s puis suivi lent ; alerte à +80 (attention) et +200 (critique) au-dessus de la ligne de base
PIR | alerte motion on/off, mélodie d'alarme, LED rouge
Panne DHT22 | 3 lectures ratées consécutives → alerte sensor_fault
Connexion MQTT | status retenu online:true , Last Will online:false publié par le broker si le boîtier disparaît
Commande cmd | buzzer , led_red , led_green , led : on / off / blink / pulse ; camera on/off : intrusion vue par l'IA → écran « ALERTE CAMERA », LED rouge, mélodie
Écran OLED | identité, IP, état MQTT et RSSI, mesures, ligne d'état : nominal / ALERTE PIR / CAMERA / CAM+PIR / gaz / temp

## 5.1 Seuils locaux

Mesure | Attention | Critique | Hystérésis
Température | > 35 °C | > 45 °C | 2 °C
Humidité | > 80 % | > 90 % | 3 %
Gaz (valeur brute 0–1023) | ligne de base + 80 | ligne de base + 200 | 30

Ces seuils sont des garde-fous « réflexe ». La détection fine d'une dérive lente et corrélée est confiée au modèle prédictif côté serveur (§ 8.2), conformément au sujet qui proscrit les simples conditions statiques.

## 5.2 Sécurité et robustesse embarquées

Session MQTTS vérifiée par l'empreinte SHA-1 du certificat serveur (épinglage), sans dépendance à une horloge réseau ; variante par CA locale disponible.
Identifiants dans include/secrets.h , exclu de Git ; le dépôt ne contient qu'un secrets.h.example .
Reconnexion Wi-Fi et MQTT automatiques avec temporisation ; le boîtier continue de mesurer et d'alerter localement hors réseau.
Mode banc d'essai ( pio run -e bench ) : radio coupée, mesures tracées sur le port série, pour câbler et tester sans réseau.

SENTINEL-X · Consortium Groupe 1 · Dossier d'ingénierie technique | Page 8 / 16

# 6 Serveur : conteneurs, API, base de données

## 6.1 Pile Docker Compose

Service | Image | Rôle | Exposition
mosquitto | eclipse-mosquitto 2.0 | broker MQTT, listener TLS 8883, listener clair 1883 (debug), mots de passe, limites anti-flood | 8883 (table), 1883 (local)
db | postgres 16-alpine | stockage, volume persistant, healthcheck | aucune
api | build local (python 3.12-slim, non root) | pont MQTT → base → WebSocket, REST, validation, clé API | 8000
dashboard | build local (node 22 → nginx 1.27) | front React, proxy /api et /ws avec injection de la clé, authentification HTTP | 8080

Mise en service : infra/scripts/bootstrap.sh <IP> génère le .env (secrets aléatoires), la CA et le certificat serveur, le fichier de mots de passe Mosquitto et celui du dashboard ; puis docker compose up -d --build .

## 6.2 Contrat de données (extrait)

Topic MQTT | Sens | Contenu
sentinel/g1/telemetry | boîtier → serveur, 5 s | {"device_id","uptime_ms","temperature","humidity","gas_raw","gas_ppm","motion","rssi","heap_free"}
sentinel/g1/alerts | boîtier → serveur | {"type","state":"on|off","value","severity":"info|warning|critical"}
sentinel/g1/status | boîtier → serveur, retenu | {"online","ip","fw"} + Last Will
sentinel/g1/cmd | serveur → boîtier | {"actuator","action","duration_ms","cmd_id"}
Méthode | Route (préfixe /api/v1 ) | Rôle | Accès
GET | /health | état API, broker, base, clients WebSocket | libre
POST | /alerts | point d'entrée obligatoire du sujet : réception d'un changement d'état | clé API
GET | /alerts , /telemetry , /telemetry/latest , /devices , /commands | historiques et état | libre (réseau de table)
POST | /commands | pilotage des actionneurs, publié sur cmd | clé API
POST | /ai/detections , /ai/predictions | résultats des scripts IA | clé API
WS | /ws | diffusion temps réel : telemetry, alert, status, command, detection, prediction | via nginx authentifié

Contrat complet : docs/CONTRAT_DONNEES.md . Documentation OpenAPI générée : /docs sur l'API.

## 6.3 Base de données

Table | Contenu | Alimentée par
devices | état du boîtier : online, IP, firmware, dernier signe de vie | status + chaque message
telemetry | mesures horodatées (index sur ts , device_id ) | MQTT, POST /telemetry
alerts | type, état, valeur, sévérité, source (esp / api / ai) | MQTT, POST /alerts, IA
commands | ordres envoyés et statut de publication | POST /commands
detections | détections de la vision : label, confiance, boîte englobante | POST /ai/detections
predictions | scores d'anomalie, fenêtre, caractéristiques | POST /ai/predictions

Schéma SQL exporté : infra/db/schema.sql . Console : infra/scripts/db-shell.sh . Volume : 17 280 lignes de télémétrie par jour, ≈ 2 Mo.

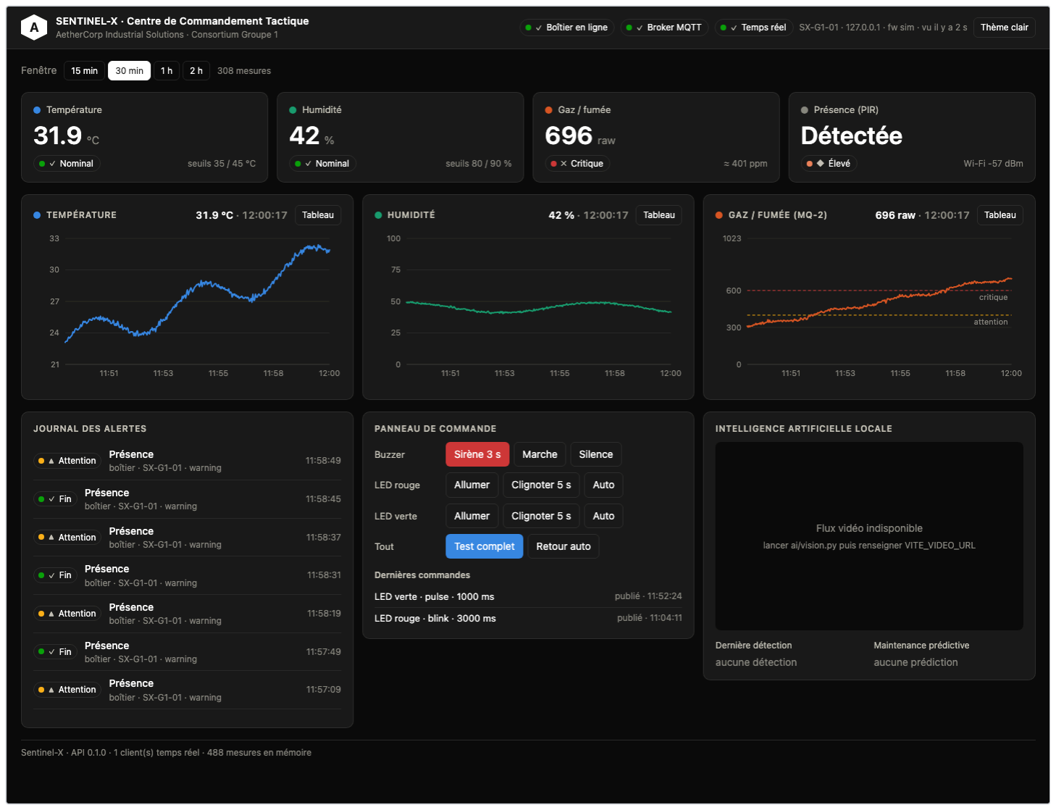
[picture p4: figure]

SENTINEL-X · Consortium Groupe 1 · Dossier d'ingénierie technique | Page 9 / 16

# 7 Dashboard de supervision

Figure 4 — Centre de Commandement Tactique : boîtier en ligne, tuiles d'état, courbes temps réel, journal, commandes, panneau IA.

Barre d'état : boîtier en ligne / hors ligne (IP, firmware, dernier signe de vie), broker MQTT, liaison temps réel.
Indicateurs : température, humidité, gaz, présence, chacun avec un statut icône + libellé (jamais la couleur seule).
Courbes : une série par graphique, seuils tracés, curseur, vue tableau pour chaque courbe, fenêtre 15 min à 2 h.
Journal des alertes : présence (PIR), intrusion (IA), gaz, température, capteur en défaut, anomalie prédictive, avec début et fin. Panneau de commande : alarme, LED rouge / verte, retour automatique ; retour « transmis au boîtier » ou « broker hors ligne ». Panneau IA : flux vidéo annoté par YOLO, dernière détection, verdict de la maintenance prédictive.
Thème clair / sombre, mise en page utilisable sur téléphone, palette validée pour les daltonismes.

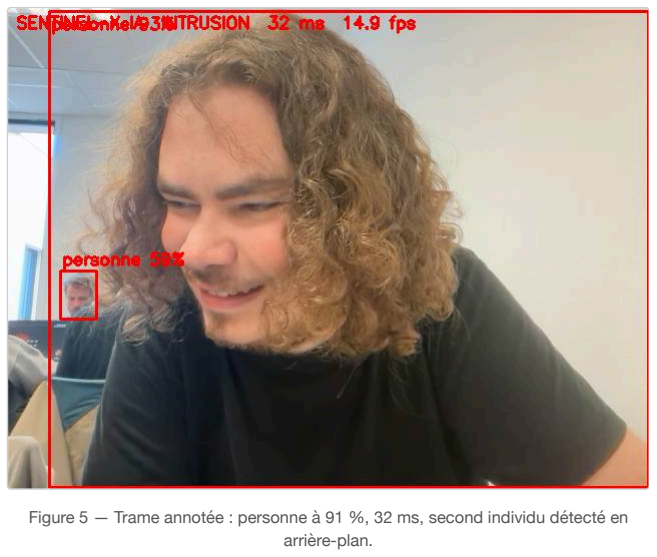
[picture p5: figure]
arrière-plan.

SENTINEL-X · Consortium Groupe 1 · Dossier d'ingénierie technique | Page 10 / 16

# 8 Intelligence artificielle locale

## 8.1 Vision : détection d'intrusion sur webcam USB

Script ai/vision.py sur le laptop : capture de la webcam USB, redimensionnement en 640×480, inférence YOLOv8n (Ultralytics, poids de 6 Mo) restreinte à la classe personne, seuil de confiance 0,5.

Personne détectée → POST /alerts type intrusion critique, commande camera on vers le boîtier (écran, LED rouge, mélodie), puis une détection toutes les 2 s.
Zone vide depuis 5 s → fin d'alerte, camera off .
Flux MJPEG annoté servi sur le port 8001, affiché dans le dashboard. Sélection de la caméra par nom (« USB ») ou menu au lancement ; la caméra intégrée du laptop n'est jamais utilisée en démo.
Mesure | Valeur
Inférence par trame | 33 ms (caméra intégrée), 32–45 ms (webcam USB 1080p redimensionnée)
Débit | 15–24 trames/s, limité par la webcam
Confiance typique | 0,84–0,93 sur une personne de face à 1–2 m

Figure 5 — Trame annotée : personne à 91 %, 32 ms, second individu détecté en

## 8.2 Maintenance prédictive : Isolation Forest sur fenêtres glissantes

Script ai/predict.py . L'historique de télémétrie est découpé en fenêtres de 300 s (pas de 60 s). Pour chaque fenêtre on calcule sept caractéristiques cinétiques :

Caractéristique | Signification
temp_mean , gas_mean | niveau moyen de température et de gaz
temp_slope , gas_slope , hum_slope | pente par minute (régression linéaire) : une hausse lente est visible bien avant un seuil
gas_std | variabilité du gaz dans la fenêtre
temp_gas_corr | corrélation température / gaz : la signature d'un incident thermique avec émission de gaz

Un Isolation Forest (200 arbres, contamination 3 %) apprend la forme « normale » des fenêtres sur les 12 dernières heures, se ré-entraîne toutes les 30 min, et score la fenêtre courante toutes les 30 s : score négatif = anomalie, alerte anomaly publiée et levée automatiquement. Premier entraînement réel : 133 fenêtres à partir de 2 042 mesures du boîtier, verdict « normal » (score +0,23). Le scénario de validation est joué avec le simulateur
( backend/tools/simulate_esp.py --drift ) qui injecte une dérive lente et simultanée de température et de gaz.

Limites assumées : le modèle n'a vu que quelques heures de fonctionnement ; il ne « comprend » pas la physique mais signale ce qui ne ressemble pas au passé récent. Les seuils réflexe du boîtier restent la dernière ligne de défense.

SENTINEL-X · Consortium Groupe 1 · Dossier d'ingénierie technique | Page 11 / 16

# 9 Sécurité : matrice, chiffrement, durcissement

## 9.1 Matrice de sécurité

Menace | Mesure en place | Preuve | État
Écoute du Wi-Fi de table (MitM, sniffing des mesures et commandes) | MQTT sur TLS 1.3 entre le boîtier et le broker ; certificat serveur épinglé par empreinte sur l'ESP | Handshake openssl s_client ci-dessous ; capture Wireshark du port 8883 à joindre jeudi (trames Application Data, aucun JSON lisible) | en place
Injection de fausses mesures ou de commandes sur le broker | Anonyme refusé, authentification par compte, topics préfixés sentinel/g1/ | mosquitto_pub sans identifiants → Connection Refused: not authorised | en place
Flood MQTT / déni de service du broker | 50 connexions max, 20 messages en vol, file de 1 000, paquets ≤ 4 Ko | infra/mosquitto/mosquitto.conf | en place
Écritures non autorisées sur l'API (fausses alertes, buzzer) | Clé API sur toutes les écritures, comparaison en temps constant, validation stricte des payloads | POST /commands sans clé → HTTP 401 ; télémétrie hors plage rejetée (observé : 125 °C refusé) | en place
Fuite de la clé API via le navigateur | La clé n'est jamais livrée au front : nginx et le serveur de dev l'injectent côté serveur | dashboard/nginx/default.conf.template | en place
Accès au dashboard par un tiers sur le réseau | Authentification HTTP, en-têtes X-Frame-Options , nosniff , version nginx masquée | GET / sans identifiants → HTTP 401 | en place
Accès direct à la base de données | Aucun port publié ; accès uniquement via le réseau Docker interne | docker compose ps : 5432/tcp non mappé | en place
Fuite de secrets par le code source | .env , mots de passe, certificats, secrets.h exclus de Git ; secrets générés aléatoirement au bootstrap | git ls-files ne contient aucun de ces fichiers | en place
Élévation de privilèges via un conteneur | API exécutée par un utilisateur non root ; base et broker sur images officielles | backend/Dockerfile | en place
Port MQTT en clair atteignable depuis le réseau | Limiter 1883 à localhost et le fermer au pare-feu | — | jeudi matin
Dashboard et API en HTTP sur le réseau de table | Mot de passe transmis en clair : restreindre l'accès au seul laptop ou passer en HTTPS avec la CA locale | — | jeudi matin
Compromission de l'hôte (laptop) | Pare-feu entrant, SSH par clés uniquement, Docker sans exposition du socket, mises à jour | — | jeudi matin (filière CYBER)
Vol physique du boîtier | Identifiants Wi-Fi et MQTT lisibles dans la flash | risque résiduel accepté : rotation du mot de passe MQTT si le boîtier disparaît | résiduel
Intrusion non détectée pendant le pentest | Détection en direct : infra/scripts/watch-attacks.sh signale les connexions d'IP non reconnues (vraie IP par lsof , hors masquage Docker), les échecs d'authentification HTTP (401/403) et MQTT, et les scans de chemins sensibles | Démonstration : un curl depuis un autre poste déclenche une ligne rouge CONNEXION INCONNUE et AUTH REFUSEE | en place

## 9.2 Preuve du chiffrement

$ openssl s_client -connect serveur:8883 -brief CONNECTION ESTABLISHED
Protocol version: TLSv1.3
Ciphersuite: TLS_AES_256_GCM_SHA384
Peer certificate: C=FR, O=AetherCorp, OU=Sentinel-X G1, CN=<ip-serveur> Hash used: SHA256 · Signature type: rsa_pss_rsae_sha256

$ openssl x509 -in infra/mosquitto/certs/server.crt -noout -issuer -dates issuer=C=FR, O=AetherCorp, OU=Sentinel-X G1, CN=Sentinel-X CA
notBefore=Oct 5 08:59:35 2026 GMT | notAfter=Oct 5 08:59:35 2027 GMT
$ mosquitto_pub -h serveur -p 1883 -t test -m x | (sans identifiants)
Connection error: Connection Refused: not authorised.
$ curl -X POST http://serveur:8000/api/v1/commands -d '{...}' | (sans clé) | → HTTP 401
$ curl http://serveur:8080/ | (sans mot de passe) → HTTP 401

Côté boîtier, le journal série confirme : [mqtt] connexion 10.108.128.150:8883 (TLS)... OK . Le certificat est signé par une autorité locale générée par le consortium ; l'ESP vérifie l'empreinte SHA-1 du certificat serveur, ce qui rend toute substitution de serveur impossible sans accès au boîtier.

## 9.3 Plan de durcissement du serveur (jeudi matin, avant le gel du code)

1. Pare-feu macOS activé, règles : autoriser 8883, 8080, 22 ; refuser le reste, dont 1883 et 8000 depuis le réseau.
2. Listener 1883 de Mosquitto lié à 127.0.0.1 ; API publiée sur 127.0.0.1:8000 uniquement, le dashboard nginx restant le seul point d'entrée.
3. SSH : authentification par clés uniquement, mot de passe désactivé, utilisateur dédié.
4. Docker : socket non exposé, images épinglées, conteneurs en lecture seule là où c'est possible.

SENTINEL-X · Consortium Groupe 1 · Dossier d'ingénierie technique | Page 12 / 16
5. Comptes MQTT distincts pour le boîtier, l'API et les scripts IA, avec droits par topic (ACL).
6. Capture Wireshark de référence sur 8883 et 1883 pour le rapport d'audit.

SENTINEL-X · Consortium Groupe 1 · Dossier d'ingénierie technique | Page 13 / 16

# 10 Rapport d'audit post-pentest

Section à compléter jeudi 8 octobre après le pentest croisé. Le gabarit ci-dessous est à remplir pour chaque test subi et chaque test mené contre une autre table.

## 10.1 Tests subis (notre infrastructure)

Attaque | Outil | Vecteur | Résultat observé | Correctif
Reconnaissance | Nmap | scan des ports du serveur depuis le réseau de table | à remplir : ports visibles, services identifiés | à remplir
Homme du milieu | Wireshark / arpspoof | interception Wi-Fi entre boîtier et serveur | à remplir : trafic 8883 illisible attendu | à remplir
Injection de payload | mosquitto_pub, curl | fausses mesures / commandes sur le broker ou l'API | à remplir : refus attendu (401, not authorised) | à remplir
Déni de service | hping3, scripts | flood MQTT / HTTP | à remplir : limites du broker, charge CPU/RAM | à remplir
Force brute | hydra | mot de passe du dashboard, comptes MQTT | à remplir | à remplir

## 10.2 Tests menés (infrastructure d'une autre table)

Cible | Attaque | Outil | Résultat | Recommandation transmise
à remplir | à remplir | à remplir | à remplir | à remplir

## 10.3 Synthèse et mesures correctives

À remplir : vulnérabilités confirmées, sévérité, correctifs appliqués avant la soutenance, risques résiduels acceptés.

SENTINEL-X · Consortium Groupe 1 · Dossier d'ingénierie technique | Page 14 / 16

# 11 Exploitation et maintien en condition opérationnelle

## 11.1 Mise en service en cinq commandes

./infra/scripts/bootstrap.sh 192.168.10.1 | # .env, CA + certificat, mots de passe
docker compose up -d --build | # broker, base, API, dashboard
cd firmware && make upload | # secrets.h renseigné : Wi-Fi, IP, empreinte
cd ai && .venv/bin/python vision.py | # webcam USB → YOLO → API
cd ai && .venv/bin/python predict.py | # maintenance prédictive

## 11.2 Contrôles avant démonstration

curl http://localhost:8000/api/v1/health → status: ok , broker et base connectés.
Dashboard : boîtier en ligne, mesures qui défilent, test du bouton « Alarme ».
Laptop sur secteur, veille désactivée ( caffeinate -dims ) : une veille de 98 min a été observée pendant les tests, le boîtier s'est reconnecté seul. heap_free dans la télémétrie ≥ 10 Ko ; valeur courante ≈ 17,6 Ko.
Caméra de continuité de l'iPhone désactivée : elle décale les index de caméra du script de vision.

## 11.3 Surveillance de la machine hôte

docker stats pour CPU/RAM des conteneurs ; journaux Mosquitto persistés dans un volume avec rotation implicite par taille de file ; docker compose logs -f api pour les payloads rejetés. En cas de redémarrage de l'hôte, restart: unless-stopped relance la pile.

Pendant la journée pentest, infra/scripts/watch-attacks.sh tourne dans un terminal : il agrège les journaux des trois services et les connexions réelles aux ports exposés, puis surligne en direct les tentatives (connexion d'une IP inconnue, authentification refusée, scan de chemins sensibles). Le trafic du Mac, du boîtier et des conteneurs est filtré ; un résumé chiffré s'affiche à l'arrêt. L'outil est en lecture seule et ne modifie aucune configuration.

## 11.4 Incidents rencontrés et résolus

Symptôme | Cause | Résolution
Port série qui disparaît à l'ouverture (macOS) | pilote CH340 natif sensible aux lignes DTR/RTS forcées | ouverture du port avec les réglages par défaut ; documenté
Carte figée, « Fatal exception (0) » en boucle | fil sur la broche EN pendant le câblage du DHT22 | recâblage sur 3V / G / D5 côté droit, reflash
Valeurs DHT22 aberrantes (125 °C) | fil de données sur D6 au lieu de D5, trames corrompues | filtre de plausibilité dans le firmware + correction du câblage
Alerte gaz permanente | seuils absolus inadaptés au MQ-2 alimenté en 3,3 V | seuils relatifs à une ligne de base auto-calibrée après 3 min de chauffe, médiane ADC
Le script de vision ouvre l'iPhone au lieu de la webcam | caméra de continuité insérée dans la liste des caméras | sélection par nom, menu au lancement, continuité désactivée en démo

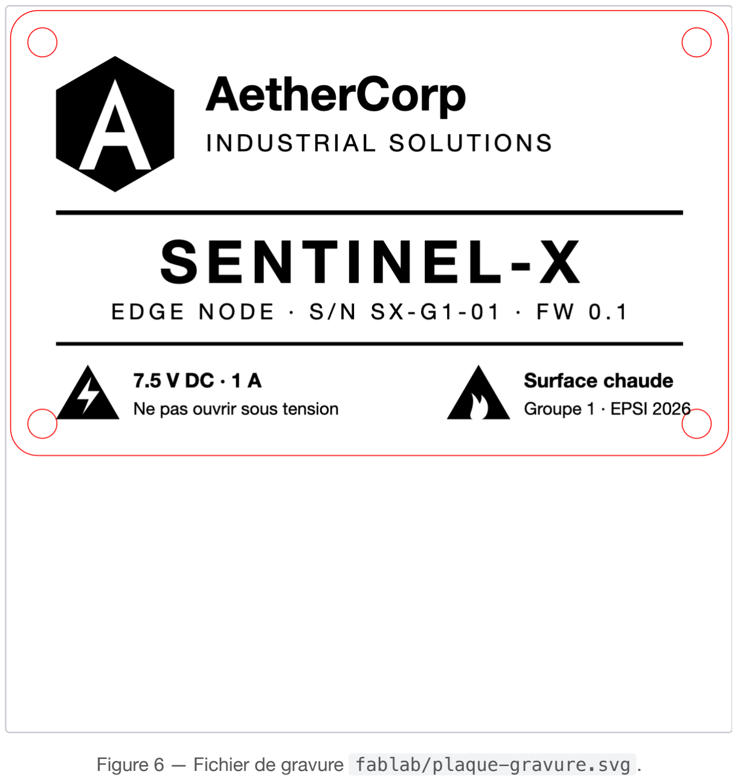
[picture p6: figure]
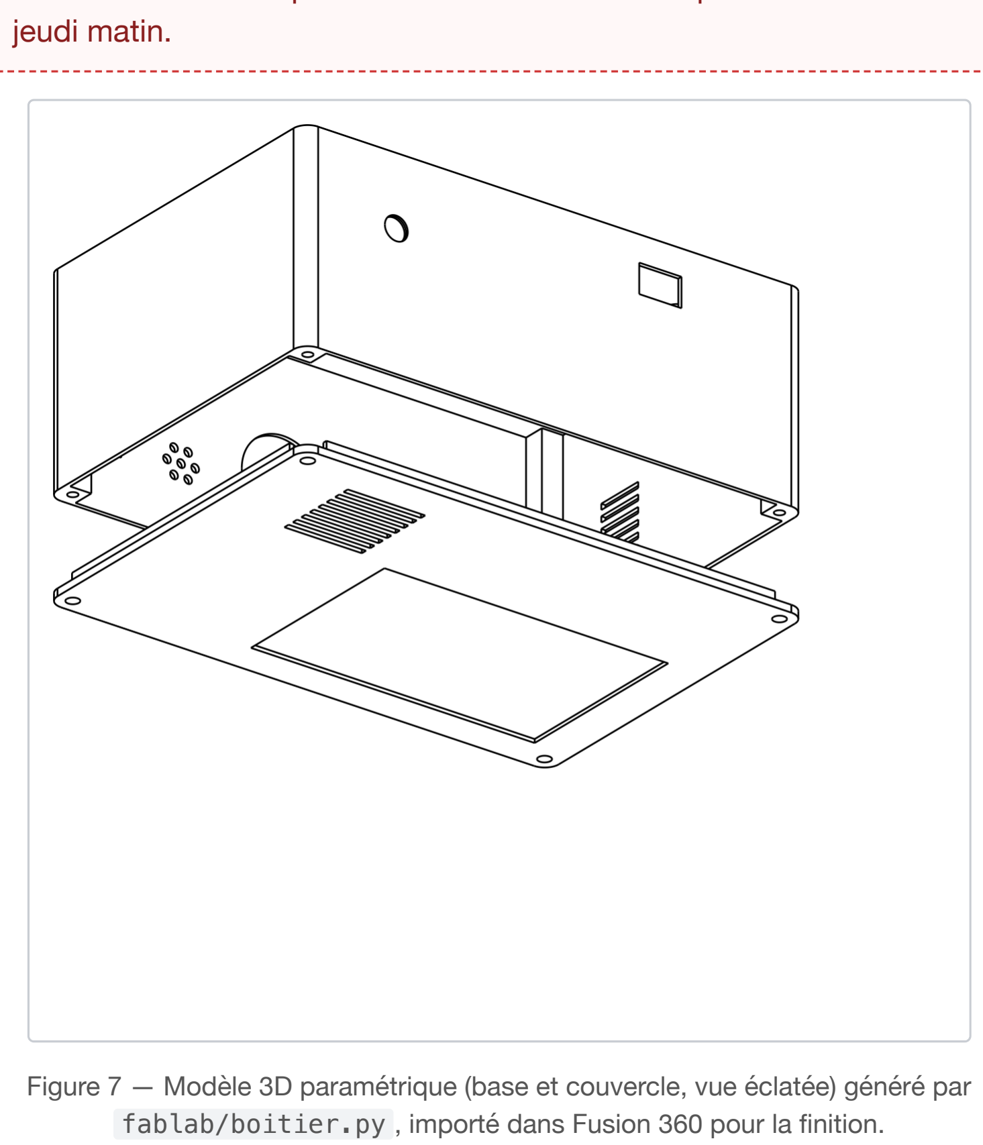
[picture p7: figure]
jeudi matin.

SENTINEL-X · Consortium Groupe 1 · Dossier d'ingénierie technique | Page 15 / 16

# 12 Fabrication numérique (Fablab)

## 12.1 Boîtier imprimé en 3D (Fusion 360, Creality K2 Plus)

Trois pièces : base avec plots pour le pack myDiL, face avant (fenêtre OLED, dôme PIR, LED, grilles buzzer et MQ-2, fentes DHT22, logement de la plaque gravée), couvercle vissé.
Parois 1,2 mm (3 lignes de buse 0,4 mm), PLA, couches 0,2 mm, remplissage 15 %, sans support grâce aux chanfreins à 45°. Passe-câbles internes : aucun fil apparent, ouverture micro-USB accessible, arrivée 7,5 V par presse-étoupe.
Le MQ-2 est isolé du DHT22 : sa capsule chauffe à ≈ 50 °C.

Photos du boîtier imprimé et assemblé à insérer après la finition de

Figure 7 — Modèle 3D paramétrique (base et couvercle, vue éclatée) généré par fablab/boitier.py , importé dans Fusion 360 pour la finition.

## 12.2 Plaque gravée au laser (Creality Falcon A1)

Plaque 80 × 50 mm, plexiglas ou contreplaqué 3 mm, fixée en face avant. Noir = gravure, rouge = découpe (contour arrondi, 4 trous M3). Contenu : logo AetherCorp, nom du produit, numéro de série SX-G1-01 , pictogrammes de sécurité (7,5 V DC, ne pas ouvrir sous tension, surface chaude).

Figure 6 — Fichier de gravure fablab/plaque-gravure.svg .

SENTINEL-X · Consortium Groupe 1 · Dossier d'ingénierie technique | Page 16 / 16

# 13 Annexe — Index du dépôt

Chemin | Contenu
README.md | démarrage rapide, structure, endpoints, sécurité, exploitation
docker-compose.yml , .env.example | pile serveur et variables (jamais de secret commité)
infra/ | configuration Mosquitto, scripts bootstrap / certificats / mots de passe / base, schéma SQL exporté
backend/ | API FastAPI (modèles, schémas, pont MQTT, WebSocket, routes), Dockerfile, simulateur d'ESP
firmware/ | projet PlatformIO : main.cpp , config.h , secrets.h.example , Makefile, mode banc
dashboard/ | application React/TypeScript, configuration nginx, Dockerfile
ai/ | vision.py , predict.py , common.py , dépendances
docs/ | contrat de données, architecture, câblage, boîtier, base de données, source de ce dossier
fablab/ | plaque de gravure SVG, exports CAO
livrables/ | dossier PDF, présentation, vidéo

Historique Git : commits sémantiques par brique ( feat(firmware) , feat(api) , feat(dashboard) , feat(ai) , docs , chore ), aucun secret ni fichier généré dans l'historique.

# WORKSHOP NATIONAL BAC+4 · EPSI · OCTOBRE 2026 · CONSORTIUM GROUPE 1

# SENTINEL-X — L'avant-poste industriel du futur

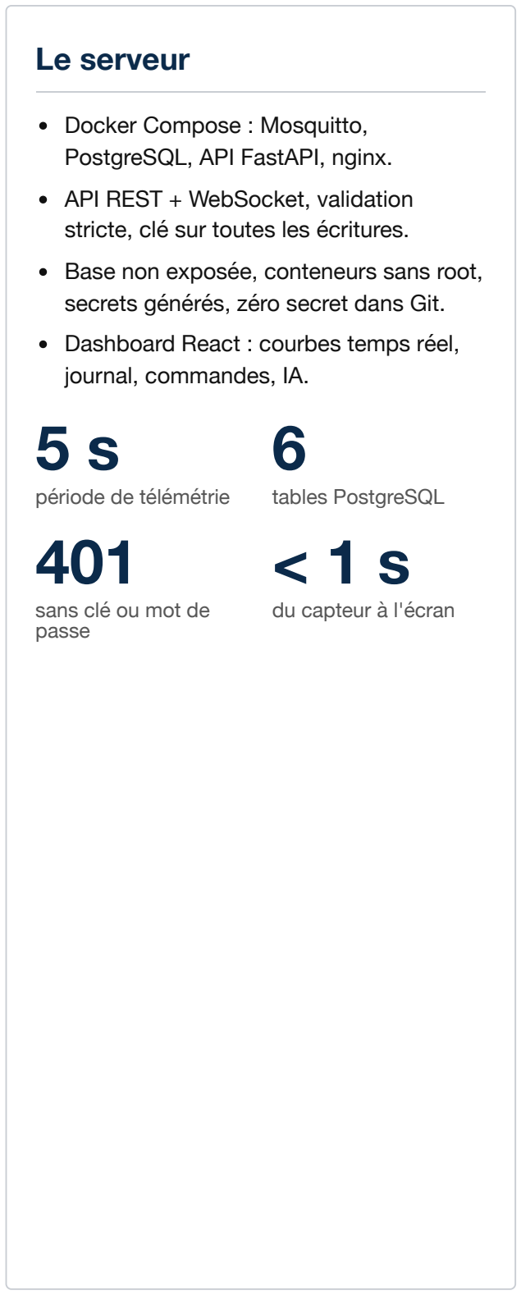
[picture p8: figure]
Le serveur; Docker Compose : Mosquitto, PostgreSQL, API FastAPI, nginx.; API REST + WebSocket, validation stricte, clé sur toutes les écritures.; Base non exposée, conteneurs sans root, secrets générés, zéro secret dans Git.; Dashboard React : courbes temps réel, journal, commandes, IA. 5 s; période de télémétrie; tables PostgreSQL; sans clé ou mot de passe; du capteur à l'écran
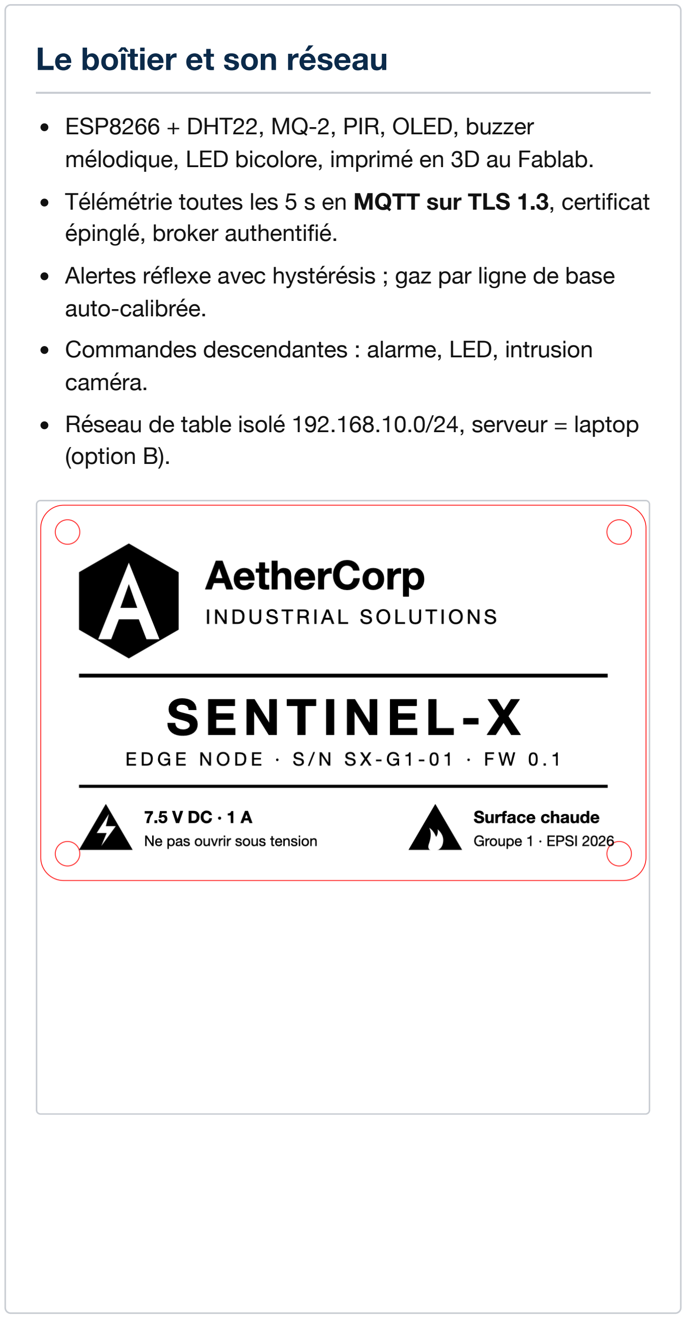
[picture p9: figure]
Le boîtier et son réseau; épinglé, broker authentifié.; auto-calibrée.; caméra.; (option B).

## ESP8266 + DHT22, MQ-2, PIR, OLED, buzzer

mélodique, LED bicolore, imprimé en 3D au Fablab.

## Télémétrie toutes les 5 s en MQTT sur TLS 1.3, certificat

## Alertes réflexe avec hystérésis ; gaz par ligne de base

## Commandes descendantes : alarme, LED, intrusion

## Réseau de table isolé 192.168.10.0/24, serveur = laptop

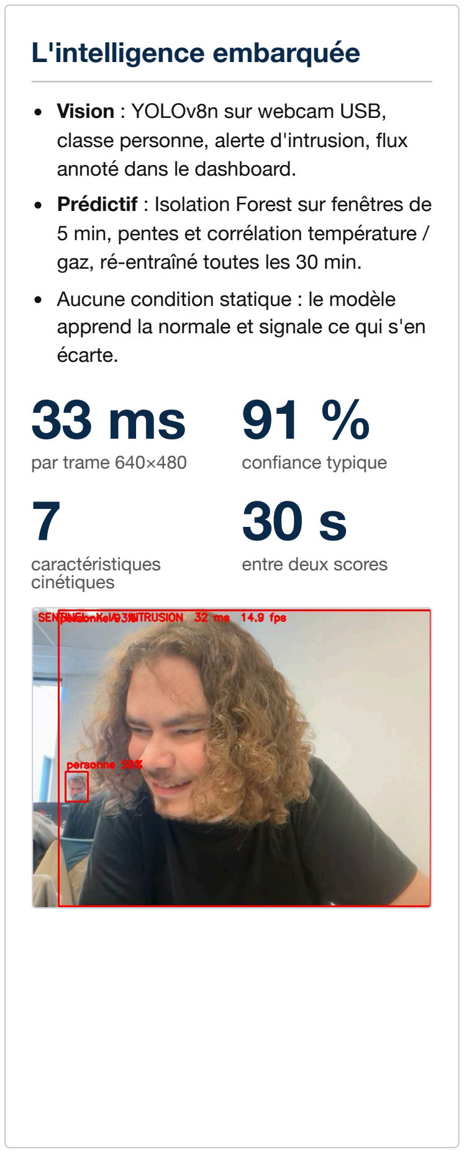
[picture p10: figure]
L'intelligence embarquée; Vision : YOLOv8n sur webcam USB,; annoté dans le dashboard.; gaz, ré-entraîné toutes les 30 min.; Aucune condition statique : le modèle; écarte. 33 ms; par trame 640×480; confiance typique; caractéristiques cinétiques; entre deux scores

## classe personne, alerte d'intrusion, flux

## Prédictif : Isolation Forest sur fenêtres de 5 min, pentes et corrélation température /

## apprend la normale et signale ce qui s'en

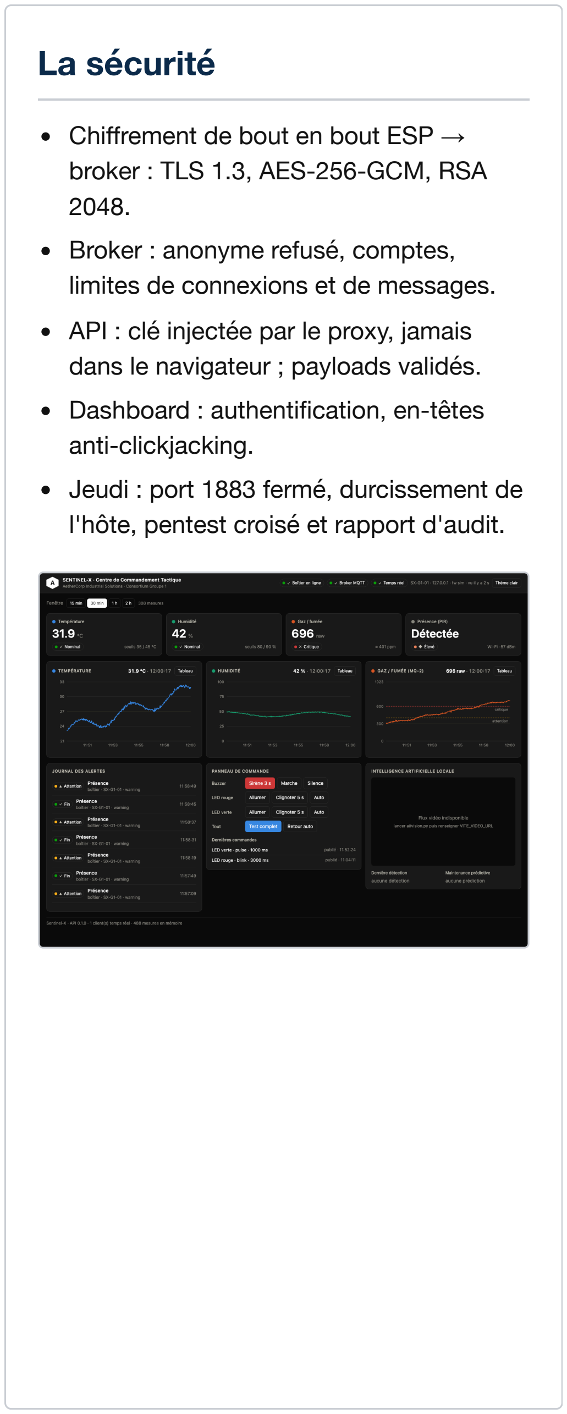
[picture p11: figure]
La sécurité; Chiffrement de bout en bout ESP → broker : TLS 1.3, AES-256-GCM, RSA 2048.; Broker : anonyme refusé, comptes, limites de connexions et de messages.; API : clé injectée par le proxy, jamais dans le navigateur ; payloads validés.; Dashboard : authentification, en-têtes anti-clickjacking.

## Jeudi : port 1883 fermé, durcissement de

l'hôte, pentest croisé et rapport d'audit.

AetherCorp Industrial Solutions · Prototype SENTINEL-X · S/N SX-G1-01 | « Sentinel-X : la sécurité à la bordure. »

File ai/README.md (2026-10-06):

# IA locale Sentinel-X

Deux scripts Python qui tournent sur le PC Serveur Local, hors Docker, pour accéder à la
webcam USB et aux ressources CPU/GPU de la machine.

```bash
cd ai
/opt/homebrew/bin/python3.12 -m venv .venv        # ou python3.12 sous Linux/Windows
.venv/bin/pip install -r requirements.txt
```

| Script | Rôle | Sortie |
|---|---|---|
| `vision.py`  | webcam → YOLOv8n (classe personne) → alerte intrusion + buzzer | `POST /ai/detections`, `POST /alerts`, flux MJPEG `:8001/stream` |
| `predict.py` | Isolation Forest sur fenêtres glissantes de télémétrie | `POST /ai/predictions`, `POST /alerts` type `anomaly` |

Les deux lisent `API_PORT` et `API_KEY` dans le `.env` à la racine. Le flux vidéo s'affiche
dans le dashboard si `VITE_VIDEO_URL=http://<ip-serveur>:8001/stream` au build du dashboard.

Premier lancement de `vision.py` : téléchargement des poids `yolov8n.pt` (6 Mo) et demande
d'autorisation caméra par macOS. Les poids sont ignorés par Git.

## Choisir la webcam

`VISION_CAMERA` dans le `.env` accepte un morceau du nom (`USB`) ou un index OpenCV. Pour
vérifier quelle caméra est laquelle, `vision.py --list` enregistre une vignette par index dans
`ai/cams/`.

Ordre des index OpenCV sur macOS, constaté : **les caméras externes d'abord** (webcam USB,
iPhone en caméra de continuité), **la caméra intégrée en dernier**. Le script applique cette
règle pour retrouver la webcam par son nom. Pour la démo, désactiver quand même la caméra de
continuité sur l'iPhone (Réglages → Général → AirPlay et Continuité) : une caméra de moins,
c'est un risque de moins.

## Personnes autorisées (reconnaissance faciale)

Chaque personne détectée par YOLO est évaluée séparément : autorisée si un visage reconnu se trouve
dans son cadre (ou l'était il y a moins de 2 s au même endroit), intruse sinon, immédiatement.
Un inconnu à côté d'une personne autorisée déclenche donc l'alerte. Détection de visage YuNet + signature SFace, modèles OpenCV dans
`ai/models/` (téléchargés automatiquement par le script de mise en place). Les signatures sont
stockées dans `ai/faces/<nom>.npy`, **jamais commitées** : ce sont des données biométriques.

```bash
.venv/bin/python enroll.py --name leo        # 20 prises en ~10 s devant la webcam
.venv/bin/python enroll.py --list
.venv/bin/python enroll.py --delete leo
.venv/bin/python vision.py                   # charge automatiquement les personnes autorisées
.venv/bin/python vision.py --no-faces        # mode « toute personne = intrusion »
```

Sur l'image annotée : silhouette et nom en vert pour une personne autorisée, silhouette rouge
« personne » pour un intrus ; le visage est cadré en vert (reconnu, similarité ≥ 0,36) ou orange (inconnu).

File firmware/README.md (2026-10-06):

# Firmware SENTINEL-X (ESP8266 NodeMCU Lolin v3)

Micrologiciel C++ (framework Arduino, PlatformIO) du boîtier. Lit DHT22, MQ-2 et PIR, affiche
l'état sur l'OLED, publie en MQTT(S) et exécute les commandes du dashboard (buzzer, LED).
Câblage : [docs/CABLAGE.md](../docs/CABLAGE.md). Interfaces : [docs/CONTRAT_DONNEES.md](../docs/CONTRAT_DONNEES.md).

## 1. Installer l'outillage

Trois façons équivalentes de compiler et flasher. Toutes reposent sur PlatformIO et partagent
le même `platformio.ini` ; choisir celle que l'on préfère, aucune n'est obligatoire.

### Option A : VS Code + extension « PlatformIO IDE » (la plus simple)

1. VS Code → Extensions → chercher « PlatformIO IDE » → Install (l'extension installe son propre Python et `pio`).
2. Fichier → Ouvrir le dossier → `firmware/`. Attendre la fin de l'initialisation (barre d'état en bas).
3. Barre d'état : icône ✓ = Build, → = Upload, prise = Serial Monitor.

### Option B : ligne de commande (CLI), sans aucun IDE

```bash
brew install platformio        # macOS ; ou : python3 -m pip install --user platformio
cd firmware
make build                     # compile
make upload                    # flashe (ESP en USB, bloc 7,5 V débranché)
make monitor                   # moniteur série 115200 bauds
```

Le `Makefile` trouve `pio` dans le PATH ou dans l'installation de l'extension VS Code.
Sous Windows sans `make` : `pio run`, `pio run -t upload`, `pio device monitor -b 115200`.

### Option C : CLion + plugin PlatformIO (méthode officielle des fiches EPSI)

Installeurs Windows dans `_Divers/` (JetBrains Toolbox, Python 3.14, `get-platformio.py`).
Fiche « Installation IDE IoT » : Toolbox → CLion → Plugins → « PlatformIO for CLion » → Open `firmware/`.
Inspections à désactiver : « Variable can be made constexpr » et « Proofreading → Typo ».

### Dans tous les cas : pilote USB et port série

- La Lolin v3 embarque un convertisseur **CH340**. macOS 12+ et Linux l'ont nativement.
  Windows : `_Divers/Windows10_CH340SER.zip` ou `Windows11_CH341SER.zip`.
- Repérer le port : `pio device list` (macOS `/dev/cu.usbserial-xxxx`, Windows « USB-SERIAL CH340 (COMx) »).
- Si la détection automatique échoue, renseigner `upload_port` / `monitor_port` dans `platformio.ini`
  ou passer `make upload PORT=COM5`.

## 2. Configurer les secrets

```bash
cp include/secrets.h.example include/secrets.h
```

Remplir `include/secrets.h` : SSID et mot de passe Wi-Fi, IP du serveur, identifiants MQTT
(ceux du `.env` du serveur) et l'empreinte du certificat affichée par `infra/scripts/gen-certs.sh`.
Pour la récupérer à tout moment :

```bash
openssl x509 -in infra/mosquitto/certs/server.crt -noout -fingerprint -sha1
```

`secrets.h` est dans `.gitignore`. Ne jamais le commiter.

## 3. Compiler, flasher, observer

```bash
cd firmware
make build        # ou : pio run
make upload       # ou : pio run -t upload      (ESP en USB, bloc 7,5 V débranché !)
make monitor      # ou : pio device monitor -b 115200
```

Sortie attendue au démarrage :

```
SENTINEL-X SX-G1-01  fw 0.1.0
[wifi] connexion a SENTINEL-G1..... OK 192.168.10.50
[mqtt] connexion 192.168.10.1:8883 (TLS)... OK
[mq2] R0 calibre = 9.12 kOhm        (après 60 s de chauffe)
```

## 3 bis. Mode banc d'essai (sans Wi-Fi)

`make bench-upload` flashe la variante `bench` : radio coupée dès le boot, pas de MQTT, et les
mesures sont tracées sur le port série toutes les 5 s (`[banc] T=.. H=.. gaz=.. pir=..`).
Pratique pour valider le câblage des capteurs et l'OLED sans réseau ni serveur. Revenir au
firmware complet avec `make upload`.

## 4. Comportement

| Événement | Firmware |
|---|---|
| Toutes les 2 s | lecture DHT22, moyenne de 8 échantillons MQ-2, état PIR |
| Toutes les 5 s | publication `sentinel/g1/telemetry` |
| Seuil franchi (contrat §6) | `sentinel/g1/alerts` state=on, escalade warning→critical, retour à off avec hystérésis |
| PIR passe à 1 / 0 | alerte `motion` on / off, sirène 3 s |
| 3 lectures DHT22 ratées de suite  | alerte `sensor_fault` |
| Alerte critique ou intrusion | buzzer 3 s automatiquement, LED rouge tant que l'alerte dure |
| Connexion MQTT | `status` retenu `online:true` + Last Will `online:false` |
| Commande sur `sentinel/g1/cmd` | `on` / `off` / `blink` / `pulse` avec `duration_ms` optionnel  |

LED verte = connecté et nominal. LED rouge = alerte active ou perte de liaison.
La commande `off` rend la main au mode automatique et coupe la sirène.

## 5. TLS : deux modes

| Mode | Avantage | Contrainte |
|---|---|---|
| **Empreinte SHA-1** (défaut)  | aucune horloge requise, fiable sur réseau isolé | à mettre à jour si le certificat change |
| **CA locale** (`MQTT_CA_CERT`)| chaîne complète, argument fort pour le jury | l'ESP a besoin de l'heure : NTP, sinon date de compilation (`BUILD_EPOCH`) |

Pour désactiver TLS en débogage : `TLS_ENABLED 0` et `MQTT_PORT 1883`. À ne jamais laisser pour la démo.

## 6. Dépannage

| Symptôme | Cause probable |
|---|---|
| `[oled] introuvable a 0x3C` | SDA/SCL inversés, ou module à 0x3D (changer `OLED_ADDR`) |
| `rc=-2` à la connexion MQTT | serveur injoignable : IP, port, pare-feu, ESP pas sur le bon Wi-Fi |
| `rc=-2` + `ssl=...` en TLS | empreinte fausse ou certificat régénéré côté serveur |
| `rc=5` | identifiants MQTT refusés (`infra/scripts/mqtt-passwd.sh`) |
| `rc=-4` | timeout : heap insuffisant pour TLS, vérifier `heap` dans le log |
| Redémarrages `wdt reset` | alimentation faible (MQ-2 + Wi-Fi) ou GPIO de boot mal tiré |
| Gaz toujours à 1023 | pas de diviseur sur A0, ou MQ-2 AO relié à DO |
| DHT22 `pas de donnee` | DATA sur la mauvaise broche, ou lecture avant 2 s |
| Port série qui disparaît sur macOS (« Device not configured ») | pilote CH340 Apple : utiliser `make monitor`, ne pas forcer DTR/RTS dans un script maison ; sinon pilote WCH |
| Carte qui redémarre dès que le Wi-Fi démarre | alimentation trop faible : port USB direct ou hub alimenté ; en attendant, `make bench-upload` (sans radio) pour tester capteurs et OLED |

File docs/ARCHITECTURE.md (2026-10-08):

# Architecture Sentinel-X — Groupe 1 (option B)

Choix validés par les coachs, figés pour le sprint.

## 1. Vue d'ensemble

```mermaid
flowchart LR
  subgraph Boitier["Boîtier SENTINEL-X (impression 3D)"]
    ESP[ESP8266 NodeMCU v3]
    DHT[DHT22<br/>temp / humidité] --> ESP
    MQ[MQ-2<br/>gaz / fumée] --> ESP
    PIR[PIR HC-SR501<br/>présence] --> ESP
    ESP --> OLED[OLED I2C 0x3C<br/>IP · Wi-Fi · statut]
    ESP --> BUZ[Buzzer actif]
    ESP --> LED[LED bicolore R/V]
  end

  subgraph Serveur["PC Serveur Local (laptop, Docker)"]
    MQTT[(Mosquitto<br/>8883 TLS)]
    API[API FastAPI<br/>:8000]
    DB[(PostgreSQL)]
    WEB[Dashboard React]
    VIS[IA vision<br/>YOLOv8-tiny]
    PRED[IA prédictive<br/>Isolation Forest]
    CAM[Webcam USB]
  end

  ESP -- "MQTTS telemetry/alerts/status" --> MQTT
  MQTT -- "cmd" --> ESP
  MQTT --> API
  API <--> DB
  API -- "WebSocket + REST" --> WEB
  CAM --> VIS
  VIS -- "POST /ai/detections" --> API
  API -- "GET /telemetry" --> PRED
  PRED -- "POST /ai/predictions" --> API
```

## 2. Réseau de table

Cible : réseau de table isolé, SSID `SENTINEL-G1`, WPA2, 2,4 GHz, serveur en `192.168.10.1` statique. Faute de routeur dédié pendant le sprint, la démonstration tourne sur un **hotspot Wi-Fi partagé** : le serveur reçoit son IP par DHCP (p. ex. `192.168.137.53`) et l'ESP la sienne (p. ex. `192.168.137.244`). L'épinglage du certificat sur l'ESP porte sur l'empreinte, pas sur l'IP, donc le changement d'adresse n'affecte pas la connexion TLS. Seuls le SSID, le mot de passe et `MQTT_HOST` (IP du serveur) sont à mettre à jour dans `firmware/include/secrets.h` puis reflasher.

| Élément | Valeur (démo sur hotspot) |
|---|---|
| Serveur (API, broker) | IP DHCP du laptop, reportée dans `MQTT_HOST` |
| ESP8266 | IP DHCP, client MQTTS uniquement |
| Postes du groupe / jury | même hotspot, dashboard par mot de passe |

Ports exposés sur le serveur (à aligner au durcissement) :

| Port  | Service | Ouvert à |
|---|---|---|
| 8883  | MQTTS | ESP8266, scripts IA |
| 1883  | MQTT clair (debug) | localhost uniquement, à fermer au durcissement |
| 8000 (→ 8010 sur l'hôte) | API REST + WebSocket | postes du groupe |
| 8080  | Dashboard (nginx, auth basic) | postes du groupe / jury |
| 22 | SSH (clés uniquement) | postes du groupe |

Détection en direct pendant le pentest : `infra/scripts/watch-attacks.sh` surligne les connexions d'IP inconnues, les échecs d'authentification HTTP/MQTT et les scans de chemins. Lecture seule.

## 3. Flux de données

1. L'ESP lit les capteurs toutes les 2 s, publie une télémétrie toutes les 5 s et une alerte à chaque franchissement de seuil local.
2. Mosquitto authentifie l'ESP (login/mot de passe, anonyme refusé) sur une session TLS que l'ESP vérifie par l'empreinte du certificat serveur (épinglage ; variante par CA locale disponible).
3. L'API s'abonne à `sentinel/g1/#`, persiste en base et pousse immédiatement l'événement aux dashboards connectés en WebSocket.
4. Le superviseur déclenche buzzer/LED depuis le dashboard : `POST /commands` → publication MQTT `sentinel/g1/cmd` → ESP.
5. Le script de vision lit la webcam (640x480), infère, et pousse chaque détection de personne à l'API.
6. Le modèle prédictif relit l'historique télémétrie, calcule un score d'anomalie sur fenêtre glissante et le pousse à l'API.

## 4. Choix justifiés

- **FastAPI** : async natif pour le WebSocket, validation Pydantic alignée sur le contrat, doc OpenAPI automatique pour le jury.
- **MQTT plutôt que HTTP depuis l'ESP** : léger, reconnexion et Last Will intégrés, un seul lien TLS à maintenir.
- **PostgreSQL** : séries temporelles simples avec index sur `ts`, suffisant pour 4 jours et exploitable par Scikit-Learn.
- **Isolation Forest** : non supervisé, pas besoin de données étiquetées d'incident, capte la corrélation lente temp + gaz exigée par le sujet.

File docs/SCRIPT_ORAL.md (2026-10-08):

# Script de soutenance — SENTINEL-X, Groupe 1

Soutenance de campus, 10 minutes chrono imposées par le sujet. Six intervenants, une partie chacun.
Remplacez les crochets `[Nom]` par les prénoms. Les indications entre *italiques* sont des gestes, pas du texte à dire.

## Qui parle quand

| Temps | Séquence | Intervenant | Rôle |
|---|---|---|---|
| 0:00–1:00 | Introduction | **[Nom 1]** | Ouvre, plante le décor AetherCorp, annonce la variante B |
| 1:00–2:00 | Projection du teaser | *(aucun, la vidéo parle)* | [Nom 1] lance la vidéo puis se range |
| 2:00–3:00 | Démo live — le boîtier | **[Nom 2]** | Montre le matériel, déclenche une alerte réelle |
| 3:00–4:00 | Démo live — le dashboard | **[Nom 3]** | Télémétrie temps réel, envoie une commande |
| 4:00–5:00 | Démo live — l'IA | **[Nom 4]** | Vision : intrus détecté, personne autorisée reconnue |
| 5:00–7:00 | Pitch — architecture | **[Nom 5]** | La chaîne de données et les choix techniques |
| 7:00–9:00 | Pitch — sécurité | **[Nom 6]** | Les quatre couches, le pentest, la conclusion |
| 9:00–10:00 | Questions | **tous** | Chacun répond sur sa partie |

Règle d'or : on se passe la parole par une phrase de relais, jamais par un blanc. On ne lit pas ses notes, on connaît ses trois idées.

---

## 0:00 – 1:00 · Introduction — [Nom 1]

*Debout, face au jury, les six alignés derrière.*

« Bonjour. Nous sommes le consortium d'ingénieurs du Groupe 1, et nous répondons à une commande d'AetherCorp.

Les centrales d'AetherCorp sont des sites critiques, souvent isolés, où une fuite de gaz, une surchauffe ou une intrusion doivent être détectées en quelques secondes, même sans connexion au cloud.

Notre réponse, c'est Sentinel-X : un module de sécurité à la bordure. Toute l'intelligence est embarquée sur place, et un serveur local traite le reste. Nous avons choisi la variante B du sujet : pas de Raspberry Pi, c'est notre poste serveur qui joue le PC local, avec les conteneurs, l'API et l'IA.

En une phrase : Sentinel-X surveille, décide et alerte sur site, sans dépendre d'internet. Place au teaser. »

*[Nom 1] lance la vidéo et se range dans la ligne.*

## 1:00 – 2:00 · Teaser « Sentinel Drop »

*La vidéo verticale de 60 secondes est projetée. Personne ne parle. On regarde le jury, pas l'écran.*

---

## 2:00 – 3:00 · Démo live, le boîtier — [Nom 2]

*Prend le boîtier en main, le montre au jury.*

« Voici Sentinel-X en vrai. Le boîtier est imprimé en 3D au Fablab et la façade est gravée au laser, avec le logo AetherCorp et le numéro de série.

À l'intérieur, un microcontrôleur ESP8266 et ses capteurs : température et humidité, gaz et fumée, et un détecteur de présence. L'écran OLED fait défiler l'état en direct : identité, réseau, mesures.

Je déclenche une alerte réelle, maintenant. *[approche un briquet non allumé du capteur de gaz, ou passe la main devant le détecteur]* Regardez l'écran : il bascule en alerte, la LED passe au rouge, et la sirène se déclenche.

Tout ça est décidé par le boîtier lui-même, sans serveur. Et cette même alerte part vers notre poste serveur. [Nom 3] va vous montrer ce qu'il en fait. »

## 3:00 – 4:00 · Démo live, le dashboard — [Nom 3]

*Devant l'écran du dashboard, déjà ouvert.*

« Côté serveur, voici le centre de commandement. L'alerte que [Nom 2] vient de déclencher est déjà là : vous la voyez apparaître en temps réel.

Le boîtier publie ses mesures toutes les cinq secondes. Le serveur les enregistre et les pousse instantanément à l'écran par WebSocket : la courbe de température, le niveau de gaz, la présence. Aucune page à recharger.

Et ça marche dans les deux sens. Je peux reprendre la main sur le boîtier. *[clique sur le bouton Alarme]* J'envoie une commande, elle traverse le serveur, et la sirène du boîtier se déclenche à distance. C'est le superviseur qui garde le contrôle.

Jusqu'ici, ce sont des seuils simples. La vraie intelligence, c'est [Nom 4] qui va vous la montrer. »

## 4:00 – 5:00 · Démo live, l'IA — [Nom 4]

*Devant la fenêtre de la caméra.*

« Sentinel-X ne se contente pas de capteurs. Une webcam surveille la zone, et une IA de vision tourne sur le serveur.

*[se place devant la caméra, ou fait passer un complice]* Quand une personne entre dans le champ, l'IA la détecte et le signale comme intrusion : le boîtier affiche « alerte caméra » et déclenche la sirène.

Mais tout le monde n'est pas un intrus. *[se montre au cadre]* Mon visage a été enregistré comme personne autorisée. L'IA me reconnaît et ne déclenche aucune alerte. Un visage inconnu, lui, lève l'alarme immédiatement.

En plus de ça, un deuxième modèle analyse l'historique des mesures et repère les dérives lentes et anormales que de simples seuils rateraient. Voilà pour la démonstration. [Nom 5] va expliquer comment tout ça tient ensemble. »

---

## 5:00 – 7:00 · Pitch, l'architecture — [Nom 5]

*Support de présentation : schéma d'architecture.*

« Ce que vous venez de voir repose sur une chaîne simple et robuste.

Le boîtier parle au serveur en MQTT, un protocole léger fait pour les objets connectés. Sur le serveur, un broker Mosquitto reçoit les messages. Une API en Python, FastAPI, les valide, les enregistre dans une base PostgreSQL, et les diffuse au dashboard React en temps réel.

Nous avons fait des choix assumés. MQTT plutôt que HTTP sur le boîtier, parce qu'il gère tout seul les reconnexions et prévient le serveur si le boîtier tombe. FastAPI parce qu'il est asynchrone, parfait pour le temps réel, et qu'il documente l'API tout seul. Toute la pile serveur tient dans des conteneurs Docker : on la démarre en une commande, elle est identique sur n'importe quelle machine.

Et surtout, tout fonctionne en local. Coupez internet, Sentinel-X continue de mesurer, de décider et d'alerter. C'est le cœur de la variante B. La robustesse de ce lien, c'est [Nom 6] qui va vous en parler, côté sécurité. »

## 7:00 – 9:00 · Pitch, la sécurité — [Nom 6]

*Support : la diapositive « Sécurité de la liaison ».*

« AetherCorp est une cible. Notre liaison est protégée par quatre couches, pas un seul verrou.

D'abord le chiffrement. Le boîtier parle au serveur en TLS 1.3. Tout le trafic est illisible pour qui écoute le Wi-Fi, même sur un réseau partagé avec d'autres équipes. Le boîtier vérifie l'empreinte du certificat : impossible de se faire passer pour notre serveur.

Ensuite l'authentification. Le broker refuse toute connexion anonyme, et chaque commande envoyée à l'API exige une clé secrète. Une tentative sans identifiants est rejetée, nous pouvons vous le montrer en direct.

Troisième couche, le cloisonnement : la base de données n'est ouverte sur aucun port, et la clé secrète ne quitte jamais le serveur.

Quatrième couche, la détection : pendant le pentest, un moniteur affiche en direct toute connexion suspecte et tout échec d'authentification.

Nous assumons nos limites, et elles sont dans notre plan de durcissement. Sentinel-X, c'est la sécurité à la bordure : embarquée, chiffrée, et qui ne lâche jamais le terrain. Merci. »

*Les six se réalignent face au jury pour les questions.*

---

## 9:00 – 10:00 · Questions

Qui répond à quoi, pour ne pas se couper la parole :

- **Matériel, capteurs, seuils, alertes** → [Nom 2]
- **Dashboard, API, base de données, temps réel** → [Nom 3] et [Nom 5]
- **IA vision et modèle prédictif** → [Nom 4]
- **Sécurité, TLS, pentest, durcissement** → [Nom 6]
- **Choix de la variante B, organisation, Fablab** → [Nom 1]

Questions probables et réponse courte prête :
- *« Que se passe-t-il si le serveur tombe ? »* → Le boîtier continue de mesurer et d'alerter localement ; à son retour, le serveur le remarque et rattrape l'état.
- *« Pourquoi pas de Raspberry Pi ? »* → Variante B du sujet : notre poste joue le serveur local, moins de matériel à maintenir pour la démo.
- *« Votre chiffrement résiste à une interception ? »* → Oui, TLS 1.3 ; une capture réseau ne montre que des données chiffrées, aucun JSON lisible.
- *« L'IA tourne où ? »* → Sur le serveur local, en edge, pas dans le cloud.

## Conseils de passage

- Répétez au moins deux fois en entier, chrono en main. Le respect du temps est noté.
- Parlez au jury, pas à l'écran ni à vos notes.
- Phrases courtes, débit calme. Mieux vaut dire moins et clair que tout et vite.
- Préparez une roue de secours pour la démo : si un capteur ne répond pas, enchaînez sur le dashboard et dites-le sans paniquer. Un incident bien géré en direct rassure plus qu'une démo parfaite récitée.

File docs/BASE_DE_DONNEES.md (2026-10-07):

# Base de données Sentinel-X (PostgreSQL 16)

## Où est le schéma

| Quoi | Où |
|---|---|
| Définition de référence (ORM) | `backend/app/models.py` (SQLAlchemy) |
| Création des tables | automatique au démarrage de l'API (`Base.metadata.create_all`) |
| Export SQL du schéma réel | `infra/db/schema.sql` (généré par `infra/scripts/db-schema-dump.sh`) |
| Données | volume Docker `pgdata`, jamais dans Git |

Il n'y a donc pas de script SQL à exécuter à la main : lancer `docker compose up` suffit.
`schema.sql` sert au dossier technique et aux outils externes.

## Tables

| Table | Rôle | Alimentée par |
|---|---|---|
| `devices` | état du boîtier (online, IP, firmware, last_seen)  | MQTT `status` + chaque message reçu |
| `telemetry` | mesures toutes les 5 s (temp, hum, gaz, PIR, RSSI, heap) | MQTT `telemetry`, `POST /telemetry` |
| `alerts` | franchissements de seuils, présence, pannes | MQTT `alerts`, `POST /alerts`, IA  |
| `commands` | ordres envoyés au boîtier (buzzer, LED) | `POST /commands` |
| `detections`  | détections de la vision IA (label, confiance, bbox) | `POST /ai/detections` |
| `predictions` | scores d'anomalie du modèle prédictif | `POST /ai/predictions` |

Toutes les tables ont un `id` auto-incrémenté et un `ts` horodaté en UTC par le serveur à la
réception. Index sur `ts` et `device_id` pour les séries temporelles.

## Ouvrir une console SQL

La base n'expose aucun port sur le laptop (choix de sécurité) : on y entre par le conteneur.

```bash
./infra/scripts/db-shell.sh                      # psql interactif
./infra/scripts/db-shell.sh -c "SELECT count(*) FROM telemetry;"
```

Pour un client graphique (DataGrip, DBeaver, TablePlus) : copier `docker-compose.override.example.yml`
en `docker-compose.override.yml` (ignoré par Git, chargé automatiquement), puis `docker compose up -d db`.
La base est alors joignable sur `127.0.0.1`, port `DB_PORT` du `.env` (5434 par défaut, le 5432 étant
souvent pris par un autre projet), base `sentinelx`, utilisateur et mot de passe `POSTGRES_*` du `.env`.
Seul le Mac y accède, pas le Wi-Fi de table. Supprimer le fichier de surcharge avant le pentest.

## Requêtes utiles

```sql
-- Dernière mesure
SELECT ts, temperature, humidity, gas_raw, motion, rssi, heap_free
FROM telemetry ORDER BY ts DESC LIMIT 1;

-- Moyennes par minute sur la dernière heure (courbes lissées, dossier)
SELECT date_trunc('minute', ts) AS minute,
       round(avg(temperature)::numeric, 2) AS temp,
       round(avg(humidity)::numeric, 1)    AS hum,
       round(avg(gas_raw))                  AS gaz
FROM telemetry
WHERE ts > now() - interval '1 hour'
GROUP BY 1 ORDER BY 1;

-- Alertes par type et sévérité
SELECT type, severity, state, count(*) FROM alerts GROUP BY 1, 2, 3 ORDER BY 1, 2, 3;

-- Jeu d'entraînement pour la maintenance prédictive (features brutes)
SELECT ts, temperature, humidity, gas_raw
FROM telemetry
WHERE temperature IS NOT NULL
ORDER BY ts;

-- Trous de télémétrie > 60 s (pertes de liaison)
SELECT ts AS reprise, lag(ts) OVER (ORDER BY ts) AS avant,
       ts - lag(ts) OVER (ORDER BY ts) AS duree
FROM telemetry
ORDER BY duree DESC NULLS LAST LIMIT 5;
```

## Volume et rétention

Une télémétrie toutes les 5 s = 17 280 lignes par jour, ≈ 2 Mo. Aucune purge nécessaire
sur la semaine du workshop. Pour vider la base sans toucher aux autres conteneurs :

```bash
docker compose down db && docker volume rm sentinel-x_pgdata && docker compose up -d
```

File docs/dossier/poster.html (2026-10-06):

Workshop national Bac+4 · EPSI · Octobre 2026 · Consortium Groupe 1

# SENTINEL-X — L'avant-poste industriel du futur

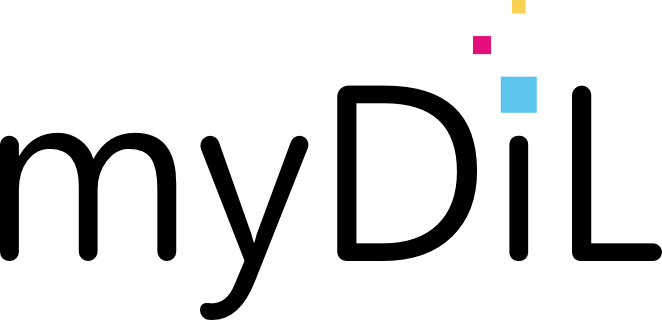
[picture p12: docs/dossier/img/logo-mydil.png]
myDiL
EPSI 

## Le boîtier et son réseau

- ESP8266 + DHT22, MQ-2, PIR, OLED, buzzer mélodique, LED bicolore, imprimé en 3D au Fablab.
- Télémétrie toutes les 5 s en MQTT sur TLS 1.3, certificat épinglé, broker authentifié.
- Alertes réflexe avec hystérésis ; gaz par ligne de base auto-calibrée.
- Commandes descendantes : alarme, LED, intrusion caméra.
- Réseau de table isolé 192.168.10.0/24, serveur = laptop (option B).

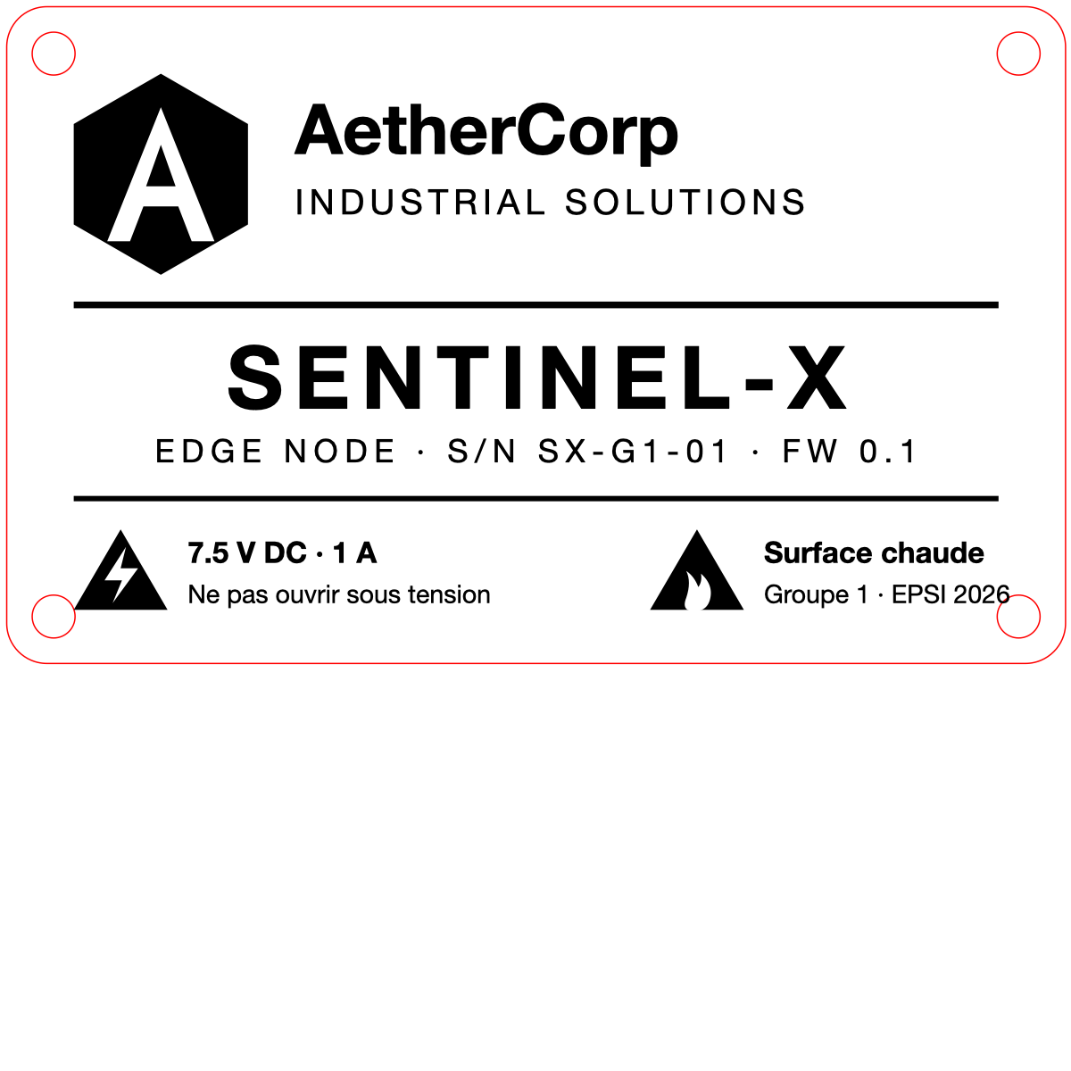
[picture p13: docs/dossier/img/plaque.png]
Plaque gravée


## Le serveur

- Docker Compose : Mosquitto, PostgreSQL, API FastAPI, nginx.
- API REST + WebSocket, validation stricte, clé sur toutes les écritures.
- Base non exposée, conteneurs sans root, secrets générés, zéro secret dans Git.
- Dashboard React : courbes temps réel, journal, commandes, IA.

5 spériode de télémétrie

6tables PostgreSQL

401sans clé ou mot de passe

< 1 sdu capteur à l'écran

## L'intelligence embarquée

- Vision : YOLOv8n sur webcam USB, classe personne, alerte d'intrusion, flux annoté dans le dashboard.
- Prédictif : Isolation Forest sur fenêtres de 5 min, pentes et corrélation température / gaz, ré-entraîné toutes les 30 min.
- Aucune condition statique : le modèle apprend la normale et signale ce qui s'en écarte.

33 mspar trame 640×480

91 %confiance typique

7caractéristiques cinétiques

30 sentre deux scores

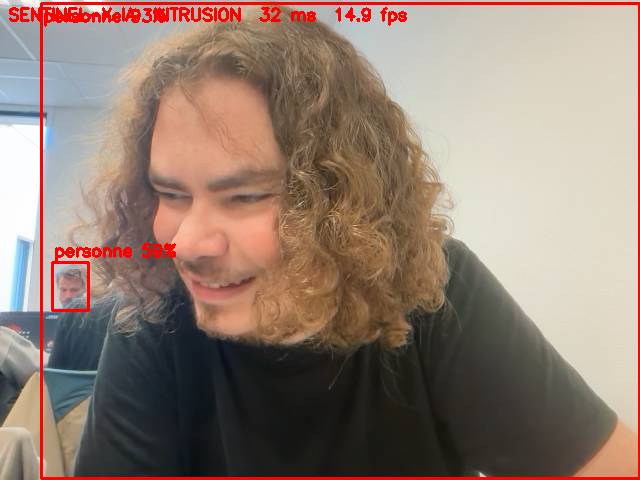
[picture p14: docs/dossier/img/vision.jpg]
Détection


## La sécurité

- Chiffrement de bout en bout ESP → broker : TLS 1.3, AES-256-GCM, RSA 2048.
- Broker : anonyme refusé, comptes, limites de connexions et de messages.
- API : clé injectée par le proxy, jamais dans le navigateur ; payloads validés.
- Dashboard : authentification, en-têtes anti-clickjacking.
- Jeudi : port 1883 fermé, durcissement de l'hôte, pentest croisé et rapport d'audit.

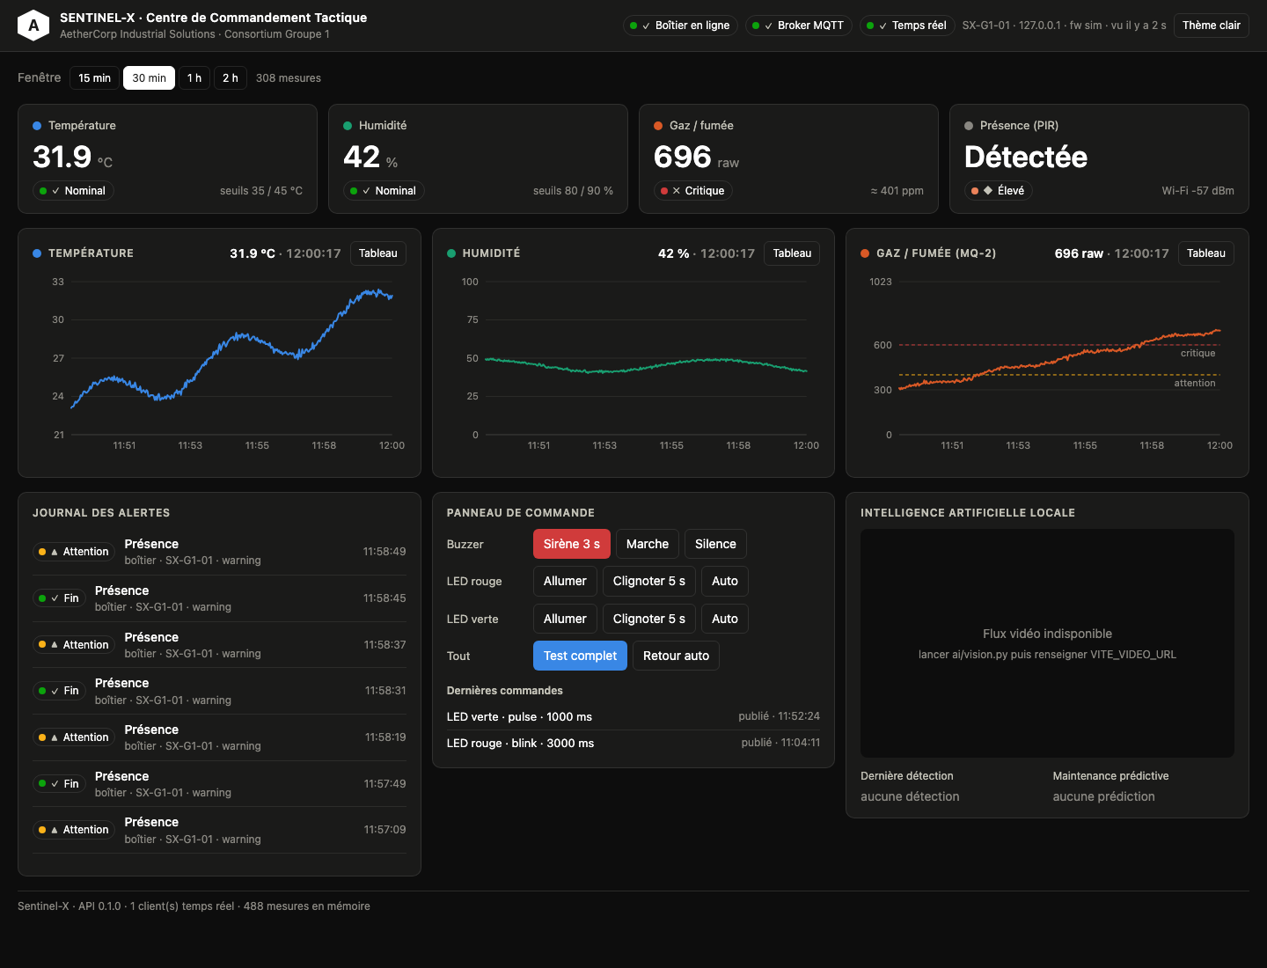
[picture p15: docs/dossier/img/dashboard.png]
Dashboard


AetherCorp Industrial Solutions · Prototype SENTINEL-X · S/N SX-G1-01« Sentinel-X : la sécurité à la bordure. »

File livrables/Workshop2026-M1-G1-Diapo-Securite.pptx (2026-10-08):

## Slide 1

Sécurité de la liaison

Du boîtier au dashboard : chiffré et authentifié de bout en bout

MQTT sur TLS

Boîtier ESP8266

client MQTTS

Capteurs temp · gaz · présence
empreinte du certificat épinglée

TLS

Serveur local (Docker)

broker · API · base

Mosquitto 8883 · FastAPI · PostgreSQL
la base n'expose aucun port

clé API

Dashboard

accès superviseur

React via nginx
mot de passe + clé API

Chiffrement

TLS 1.2 et plus de bout en bout. Trafic Wi-Fi illisible, même sur un réseau partagé.

Preuve (sans identifiants)

Authentification

Anonyme MQTT refusé. Toute écriture API exige une clé.

Cloisonnement

Base sans port exposé. La clé API reste côté serveur, jamais dans le navigateur.

Détection live

watch-attacks.sh affiche en direct les IP inconnues, échecs d'auth et scans.

mosquitto_pub sans login → not authorised POST /commands sans clé → 401 GET / sans mot de passe → 401

SENTINEL-X · Groupe 1 · liaison boîtier → serveur

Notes: Message : la liaison est sûre par couches, pas par un seul verrou.
1) Chiffrement : le boîtier parle au serveur en MQTT sur TLS (1.2 sur l'ESP8266, 1.3 côté serveur). Même sur le hotspot partagé avec les autres groupes, nos mesures et nos commandes sont illisibles au sniffing. L'ESP épingle l'empreinte du certificat, donc impossible de se faire passer pour le serveur.
2) Authentification : le broker refuse l'anonyme ; toute écriture sur l'API demande une clé. Démo : un pub ou un POST sans identifiants est rejeté.
3) Cloisonnement : la base n'a aucun port ouvert, et la clé API reste côté serveur, jamais dans le navigateur.
4) Détection : pendant le pentest, watch-attacks.sh affiche en direct les connexions d'IP inconnues et les échecs d'auth.
Limites assumées : HTTP en clair sur le réseau et secrets lisibles dans la flash du boîtier ; traités dans le plan de durcissement.

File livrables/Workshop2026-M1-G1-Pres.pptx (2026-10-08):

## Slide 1

SENTINEL-X

La sécurité à la bordure

Module de surveillance embarqué pour les centrales AetherCorp

Consortium d'ingénieurs Groupe 1 · Variante B · EPSI M1 · Workshop 2026-27

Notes: Intervenant 1, 0:00 à 1:00. Décor AetherCorp, variante B, une phrase de promesse, puis lancer le teaser.

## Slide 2

La menace

Des sites critiques, isolés, où chaque seconde compte

Les centrales AetherCorp sont des sites sensibles, souvent loin de tout réseau. Une fuite de gaz, une surchauffe ou une intrusion doivent être détectées en quelques secondes.
Attendre un serveur distant n'est pas une option : la décision doit se prendre sur place.

Détecter en secondes, sur site, sans cloud.

Gaz et fumée

Capteur MQ-2 calibré sur l'air ambiant : alerte dès une hausse anormale, deux niveaux de gravité.

Surchauffe

Température et humidité relevées toutes les 2 secondes, seuils d'attention et critiques avec hystérésis.

Intrusion

Détecteur de présence dans le boîtier et vision par caméra côté serveur, avec reconnaissance des personnes autorisées.

SENTINEL-X · Consortium Groupe 1 · Variante B

2 / 9

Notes: Soutien de l'introduction. Trois risques, une promesse : détecter sur site sans dépendre du cloud.

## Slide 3

Teaser « Sentinel Drop »

Vidéo verticale · 60 secondes

Projection de 1:00 à 2:00

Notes: Personne ne parle pendant la vidéo. On regarde le jury, pas l'écran.

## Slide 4

Le boîtier

Six composants, imprimé en 3D au Fablab, façade gravée au laser

ESP8266 NodeMCU

Le cerveau : lit les capteurs, décide, parle en Wi-Fi au serveur.

DHT22

Température et humidité, relevé toutes les 2 secondes.

MQ-2

Gaz et fumée, seuils relatifs à l'air ambiant après chauffe.

Capteur PIR

Présence : toute personne dans la zone déclenche l'alerte.

Fablab

Écran OLED

État en direct : réseau, mesures, alertes, pages qui défilent.

LED et buzzer

Vert nominal, rouge en alerte ; sirène mélodique commandable à distance.

Boîtier en trois pièces en PLA (Fusion 360, Creality K2 Plus) et plaque gravée au laser (Creality Falcon A1) : logo AetherCorp, consignes de sécurité, numéro de série. Un produit fini, pas une maquette.

SENTINEL-X · Consortium Groupe 1 · Variante B

4 / 9

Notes: Intervenant 2, 2:00 à 3:00. Le boîtier en main, puis déclencher une alerte réelle : écran en alerte, LED rouge, sirène.

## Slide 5

Démo en direct

Trois minutes, trois preuves

Le boîtier

Une alerte réelle, gaz ou présence.
L'écran bascule en alerte, la LED passe au rouge, la sirène se déclenche.
Décidé sur place, sans serveur.

1

Le dashboard

L'alerte arrive en temps réel.
Mesures toutes les 5 secondes, courbes en direct.
Une commande repart : la sirène sonne à distance.

2

L'IA

Une personne entre dans le champ : intrusion signalée au boîtier.
Un visage enregistré : aucune alerte.
Un visage inconnu : alerte immédiate.

3

Plan de secours : si un capteur ne répond pas, on enchaîne sur le dashboard et on le dit calmement.

SENTINEL-X · Consortium Groupe 1 · Variante B

5 / 9

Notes: Intervenants 2, 3 et 4, de 2:00 à 5:00. Cette diapo reste affichée pendant la démonstration ; on montre le vrai matériel et le vrai dashboard.

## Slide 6

L'intelligence embarquée

Sur le serveur local, jamais dans le cloud

Vision

YOLOv8n détecte toute personne dans le champ de la webcam USB. Chaque détection remonte à l'API et déclenche l'alerte caméra sur le boîtier.

Reconnaissance faciale

Les visages enregistrés sont des personnes autorisées : aucune alerte. Un visage inconnu est un intrus : alerte immédiate.

Maintenance prédictive

Isolation Forest sur l'historique des mesures : repère une dérive lente et corrélée de température et de gaz que des seuils fixes rateraient.

33 ms

par image, YOLOv8n sur processeur

6 Mo

modèle de vision embarqué

5 s

entre deux télémétries du boîtier

SENTINEL-X · Consortium Groupe 1 · Variante B

6 / 9

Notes: Intervenant 4, 4:00 à 5:00. Vision, reconnaissance des personnes autorisées, puis le modèle prédictif sur l'historique.

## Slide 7

Architecture

Une chaîne simple, entièrement locale

Boîtier ESP8266

capteurs · décision locale

Mosquitto

broker MQTTS · port 8883

API FastAPI

validation · WebSocket

PostgreSQL

historique des mesures

Dashboard React

nginx · mot de passe

Scripts IA : vision et prédictif → API

MQTT plutôt que HTTP

Léger, reconnexion automatique, Last Will : le serveur sait quand le boîtier disparaît.

FastAPI et PostgreSQL

Asynchrone pour le temps réel, validation stricte des données, API documentée automatiquement.

Docker Compose

Toute la pile démarre en une commande et tourne à l'identique sur n'importe quelle machine.

Coupez internet : SENTINEL-X continue de mesurer, de décider et d'alerter.

SENTINEL-X · Consortium Groupe 1 · Variante B

7 / 9

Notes: Intervenant 5, 5:00 à 7:00. La chaîne de données de gauche à droite, puis les trois choix assumés, puis la phrase clé sur le fonctionnement hors ligne.

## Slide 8

Sécurité de la liaison

Quatre couches, pas un seul verrou

MQTT sur TLS

Boîtier ESP8266

client MQTTS

empreinte du certificat épinglée
identifiants hors du dépôt Git

TLS

Serveur local (Docker)

broker · API · base

anonyme refusé · clé API obligatoire
la base n'expose aucun port

clé API

Dashboard

accès superviseur

mot de passe nginx
clé API injectée côté serveur

Chiffrement

TLS 1.2 et plus de bout en bout. Trafic Wi-Fi illisible, même sur un réseau partagé.

Preuve, sans identifiants

Authentification

Anonyme MQTT refusé. Toute écriture sur l'API exige une clé.

Cloisonnement

Base sans port exposé. La clé API reste côté serveur, jamais dans le navigateur.

Détection live

Un moniteur affiche en direct les IP inconnues, les échecs d'authentification et les scans.

mosquitto_pub sans login → not authorised POST /commands sans clé → 401 GET / sans mot de passe → 401

Limites assumées et traitées dans le plan de durcissement : dashboard en HTTP, secrets lisibles dans la flash du boîtier.

SENTINEL-X · Consortium Groupe 1 · Variante B

8 / 9

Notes: Intervenant 6, 7:00 à 9:00. Chiffrement, authentification, cloisonnement, détection. Dire les limites avant qu'on nous les demande, puis conclure.

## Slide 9

Sentinel-X : la sécurité à la bordure.

Embarquée

décide sur site, sans cloud

Chiffrée

TLS de bout en bout, accès authentifiés

Fiable

fonctionne hors ligne, se reconnecte seule

Merci. Vos questions.

Consortium d'ingénieurs Groupe 1 · EPSI M1 · Workshop 2026-27

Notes: Fin de la partie de l'intervenant 6, puis les six se réalignent face au jury. Questions : chacun répond sur sa partie (voir SCRIPT_ORAL.md).

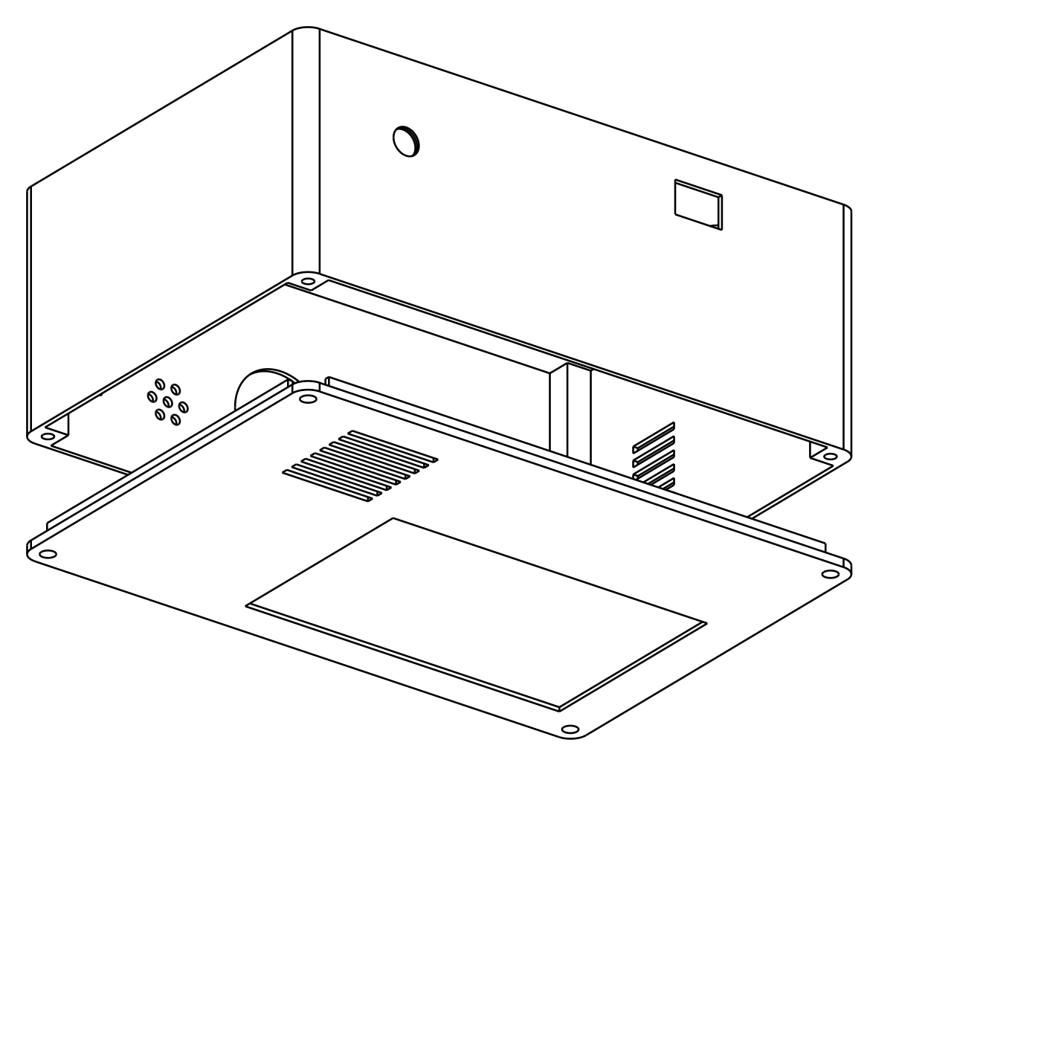
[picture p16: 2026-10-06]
docs/dossier/img/boitier-cao.png

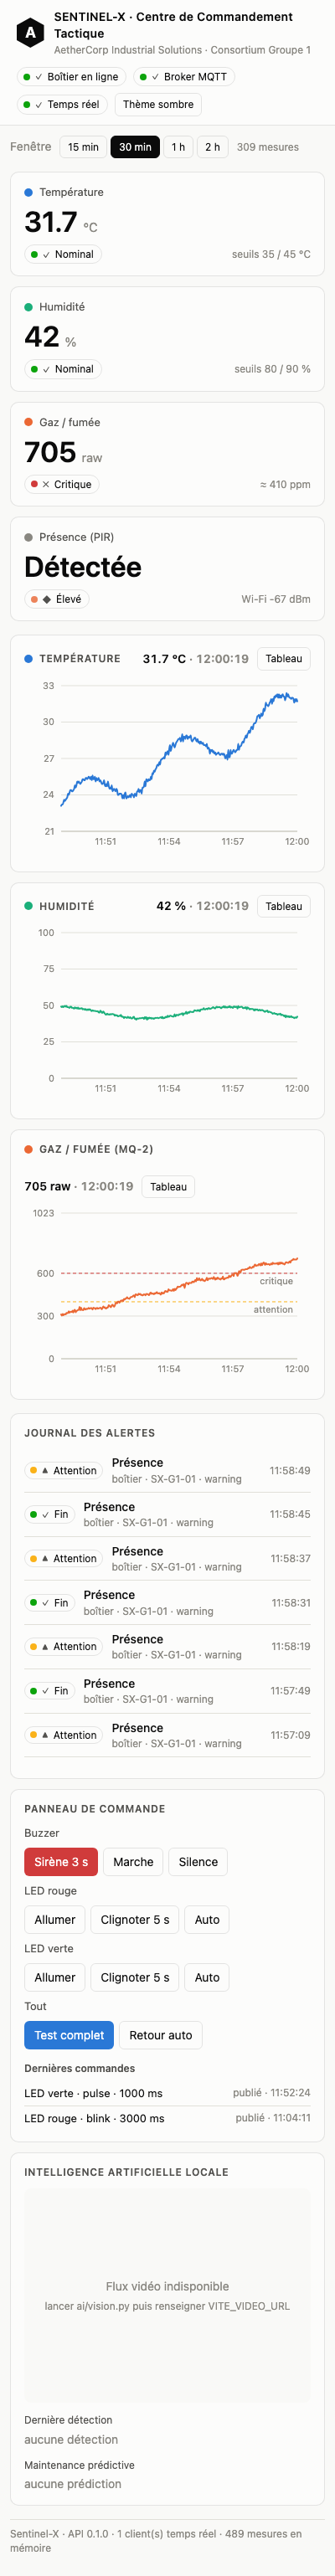
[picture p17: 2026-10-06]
docs/dossier/img/dashboard-mobile.png

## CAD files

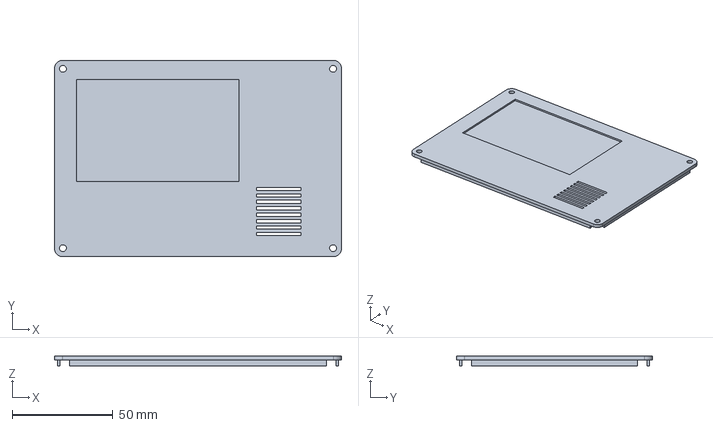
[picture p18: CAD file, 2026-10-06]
fablab/export/couvercle.step
142.4 x 97.4 x 5.00 mm

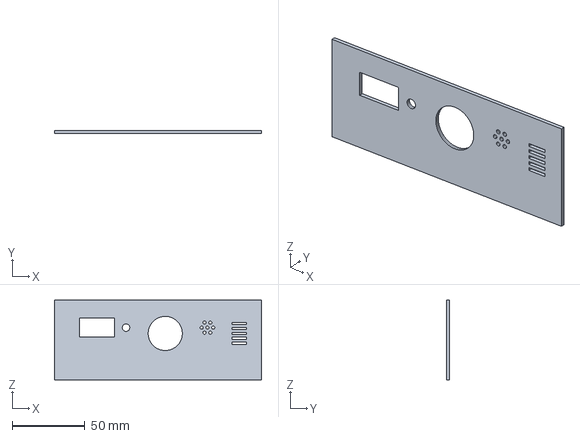
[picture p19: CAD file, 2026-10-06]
fablab/export/gabarit-face.step
142.4 x 2.00 x 55.0 mm

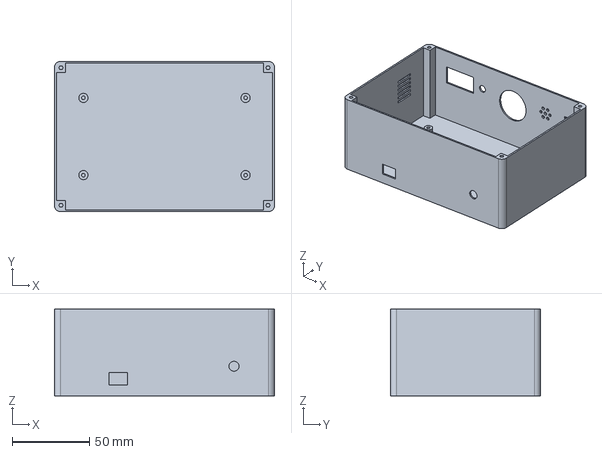
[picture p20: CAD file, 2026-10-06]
fablab/export/base.step
142.4 x 97.4 x 56.2 mm

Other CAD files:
fablab/export/base.stl
fablab/export/couvercle.stl
fablab/export/gabarit-face.stl

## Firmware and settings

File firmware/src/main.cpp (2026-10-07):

/**
 * SENTINEL-X — firmware ESP8266 (Groupe 1, AetherCorp Industrial Solutions)
 *
 * Capteurs  : DHT22 (D5), MQ-2 (A0 via diviseur), PIR HC-SR501 (D6)
 * Sorties   : OLED I2C 0x3C (D1/D2), buzzer actif (D7), LED bicolore (D0 rouge, D8 verte)
 * Réseau    : Wi-Fi + MQTT(S) vers le PC Serveur Local. Interfaces : docs/CONTRAT_DONNEES.md
 *
 * Boucle non bloquante (millis) : lecture capteurs 2 s, télémétrie 5 s, alertes sur
 * franchissement de seuil avec hystérésis, commandes reçues sur <prefix>/cmd.
 */
#include <Arduino.h>
#include <ESP8266WiFi.h>
#include <WiFiClientSecure.h>
#include <PubSubClient.h>
#include <ArduinoJson.h>
#include <Wire.h>
#include <Adafruit_GFX.h>
#include <Adafruit_SSD1306.h>
#include <DHT.h>
#include <sys/time.h>
#include <time.h>

#include "config.h"
#include "secrets.h"

// Courant de démarrage : l'ESP8266 calibre sa radio au boot (pic 300-400 mA) avant setup().
// RF_DISABLED (mode banc) : radio jamais initialisée, boot le plus sobre possible.
// RF_NO_CAL (mode normal) : radio active sans recalibration au boot, pic réduit.
#ifdef BENCH_NO_WIFI
RF_MODE(RF_DISABLED)
#else
RF_MODE(RF_NO_CAL)
#endif

// ----------------------------------------------------------------------------- objets
DHT dht(PIN_DHT, DHT_TYPE);
Adafruit_SSD1306 oled(OLED_W, OLED_H, &Wire, -1);
#if TLS_ENABLED
BearSSL::WiFiClientSecure net;
#ifdef MQTT_CA_CERT
BearSSL::X509List caList(MQTT_CA_CERT);
#endif
#else
WiFiClient net;
#endif
PubSubClient mqtt(net);

// ----------------------------------------------------------------------------- état
struct Readings {
  float temp = NAN, hum = NAN;   // dernières valeurs valides du DHT22
  uint8_t dhtFails = 0;          // lectures ratées consécutives (>= 3 → panne)
  int gasRaw = 0;
  float gasPpm = 0;
  bool motion = false;
  bool pirSeenLow = false;       // le PIR a été vu au niveau bas au moins une fois : capteur réellement branché
} rd;

struct Alerts {
  bool motion = false;
  bool gas = false, gasCrit = false;
  bool temp = false, tempCrit = false;
  bool hum = false, humCrit = false;
  bool fault = false;
  bool camera = false;   // intrusion vue par l'IA (commande "camera" envoyée par le serveur)
  bool any() const { return motion || gas || temp || hum || fault || camera; }
} al;

struct Actuator {
  uint8_t pin;
  bool manual = false;      // true : piloté par une commande ; false : mode automatique
  bool level = false;
  bool blink = false;
  unsigned long until = 0;  // fin du mode manuel (0 = jusqu'à la prochaine commande)
  unsigned long lastToggle = 0;
};
Actuator buzzer{PIN_BUZZER}, ledR{PIN_LED_RED}, ledG{PIN_LED_GREEN};
unsigned long buzzerAutoUntil = 0;

// ---- Mélodie d'alarme : sonnerie d'appel Skype, transcrite de l'enregistrement original (archive.org,
// analyse spectrale) et croisée avec la partition 2 mesures (flat.io) : glissando montant, Mib Sib Mib (Solb Reb)
// | Sib Re Sib (Lab Sib Sib) Mib. Jouée une octave au-dessus (buzzer plus sonore). Une boucle = 3.64 s,
// rejouée tant que la sirène est active. Triplets (fréquence Hz, créneau ms, durée sonnée ms). ----
static const uint16_t MELODY[] PROGMEM = {
  415,18,18, 440,18,18, 466,18,18, 494,18,18, 523,18,18,
  554,18,18, 587,18,18, 622,330,300, 932,420,380, 622,330,150,
  698,40,40, 740,250,110, 1109,450,90, 932,470,420, 587,310,280,
  932,350,150, 1661,60,55, 932,80,60, 932,190,70, 622,230,200 };
static const uint8_t MELODY_LEN = sizeof(MELODY) / sizeof(MELODY[0]) / 3;   // nombre de notes

struct Melody {
  bool playing = false;
  uint8_t idx = 0;
  unsigned long nextAt = 0;
} melody;

static void melodyStop() {
  noTone(PIN_BUZZER);
  melody.playing = false;
}

static void melodyStart(unsigned long now) {
  melody.playing = true;
  melody.idx = 0;
  melody.nextAt = now;           // la première note part au prochain tick
}

// Avance la mélodie sans bloquer ; la rejoue en boucle tant qu'on ne l'arrête pas.
static void melodyTick(unsigned long now) {
  if (!melody.playing || now < melody.nextAt) return;
  if (melody.idx >= MELODY_LEN) melody.idx = 0;
  uint16_t f    = pgm_read_word(&MELODY[melody.idx * 3]);
  uint32_t slot = (uint32_t)pgm_read_word(&MELODY[melody.idx * 3 + 1]) * MELODY_SPEED_PCT / 100;
  uint32_t snd  = (uint32_t)pgm_read_word(&MELODY[melody.idx * 3 + 2]) * MELODY_SPEED_PCT / 100;
  if (f) tone(PIN_BUZZER, f, snd); else noTone(PIN_BUZZER);
  melody.nextAt = now + slot;
  melody.idx++;
}

bool oledOk = false;
uint8_t oledAddr = OLED_ADDR;
unsigned long oledProbeAt = 0;

// Cherche l'écran aux adresses 0x3C puis 0x3D ; appelé au boot puis toutes les 10 s tant qu'il manque.
static bool oledProbe() {
  for (uint8_t a : {(uint8_t)0x3C, (uint8_t)0x3D}) {
    Wire.beginTransmission(a);
    if (Wire.endTransmission() == 0 && oled.begin(SSD1306_SWITCHCAPVCC, a)) { oledAddr = a; return true; }
  }
  return false;
}
float mq2R0 = 0;   // résistance du MQ-2 en air propre, calibrée après la chauffe
float gasBase = -1;   // ligne de base du MQ-2 (valeur brute en air propre), fixée après la chauffe
unsigned long tSensor = 0, tTelemetry = 0, tOled = 0, tMqttRetry = 0, bootMs = 0;

static String topic(const char* suffix) { return String(TOPIC_PREFIX) + "/" + suffix; }
static bool dhtFault() { return rd.dhtFails >= 3; }
static bool dhtValid() { return !isnan(rd.temp) && !dhtFault(); }

// ----------------------------------------------------------------------------- OLED
// Interface en pages (128x64) : bandeau titre, pictogrammes, gros chiffres, jauge, courbe,
// pagination en bas. Les pages défilent toutes les OLED_PAGE_MS ; une alerte prend l'écran et clignote.
static const uint8_t ICON_THERMO[] PROGMEM = { 0x03,0xC0, 0x04,0x20, 0x05,0xA0, 0x05,0xA0, 0x05,0xA0, 0x05,0xA0, 0x05,0xA0, 0x05,0xA0, 0x05,0xA0, 0x09,0x90, 0x13,0xC8, 0x17,0xE8, 0x17,0xE8, 0x0B,0xD0, 0x04,0x20, 0x03,0xC0 };
static const uint8_t ICON_DROP[] PROGMEM = { 0x01,0x00, 0x01,0x00, 0x03,0x80, 0x03,0x80, 0x07,0xC0, 0x07,0xC0, 0x0F,0xE0, 0x0F,0xE0, 0x1F,0xF0, 0x1F,0xF0, 0x1F,0xF0, 0x1E,0xF0, 0x0E,0xE0, 0x0F,0xE0, 0x07,0xC0, 0x03,0x80 };
static const uint8_t ICON_FLAME[] PROGMEM = { 0x01,0x00, 0x03,0x00, 0x03,0x80, 0x07,0x80, 0x07,0xC0, 0x0F,0xC0, 0x0F,0xE0, 0x1F,0xE0, 0x1F,0xF0, 0x1E,0xF0, 0x3C,0x78, 0x3C,0x78, 0x3E,0xF8, 0x1F,0xF0, 0x0F,0xE0, 0x07,0xC0 };
static const uint8_t ICON_PERSON[] PROGMEM = { 0x03,0xC0, 0x07,0xE0, 0x07,0xE0, 0x07,0xE0, 0x03,0xC0, 0x01,0x80, 0x0F,0xF0, 0x1F,0xF8, 0x3F,0xFC, 0x3B,0xDC, 0x3B,0xDC, 0x3B,0xDC, 0x03,0xC0, 0x03,0xC0, 0x07,0xE0, 0x07,0xE0 };
static const uint8_t ICON_CAMERA[] PROGMEM = { 0x00,0x00, 0x07,0x80, 0x0F,0xC0, 0x7F,0xF0, 0x7F,0xFC, 0x60,0x0C, 0x67,0xCC, 0x6F,0xEC, 0x6C,0x6C, 0x6C,0x6C, 0x6F,0xEC, 0x67,0xCC, 0x60,0x0C, 0x7F,0xFC, 0x3F,0xF8, 0x00,0x00 };
static const uint8_t ICON_SHIELD[] PROGMEM = { 0x01,0x80, 0x07,0xE0, 0x1F,0xF8, 0x3F,0xFC, 0x39,0x9C, 0x3B,0xDC, 0x3B,0xDC, 0x3B,0xDC, 0x38,0x1C, 0x3B,0xDC, 0x3F,0xFC, 0x1F,0xF8, 0x0F,0xF0, 0x07,0xE0, 0x03,0xC0, 0x01,0x80 };
static const uint8_t ICON_WARN[] PROGMEM = { 0x01,0x80, 0x01,0x80, 0x03,0xC0, 0x03,0xC0, 0x06,0x60, 0x06,0x60, 0x0E,0x70, 0x0E,0x70, 0x1E,0x78, 0x1E,0x78, 0x3E,0x7C, 0x3F,0xFC, 0x7E,0x7E, 0x7E,0x7E, 0xFF,0xFF, 0x00,0x00 };

#define OLED_PAGE_MS 7000
#define TEMP_HIST_N 48
float tempHist[TEMP_HIST_N];
uint8_t tempHistN = 0, tempHistHead = 0;
uint8_t oledPage = 0;
unsigned long oledPageSince = 0;
bool oledInverted = false;

static void histPush(float v) {
  tempHist[tempHistHead] = v;
  tempHistHead = (tempHistHead + 1) % TEMP_HIST_N;
  if (tempHistN < TEMP_HIST_N) tempHistN++;
}

static void drawHeader(const char* title) {
  oled.fillRoundRect(0, 0, 128, 11, 2, SSD1306_WHITE);
  oled.setTextSize(1);
  oled.setTextColor(SSD1306_BLACK);
  oled.setCursor(3, 2);
  oled.print(title);
  // Wi-Fi : 4 barres selon le RSSI
  int bars = !WiFi.isConnected() ? 0 : (WiFi.RSSI() > -55 ? 4 : WiFi.RSSI() > -65 ? 3 : WiFi.RSSI() > -75 ? 2 : 1);
  for (int i = 0; i < 4; i++) {
    int h = 2 + i * 2, x = 104 + i * 3;
    if (i < bars) oled.fillRect(x, 9 - h, 2, h, SSD1306_BLACK);
    else oled.drawRect(x, 9 - h, 2, h, SSD1306_BLACK);
  }
  // MQTT : point plein si connecté, vide sinon
  if (mqtt.connected()) oled.fillCircle(122, 5, 3, SSD1306_BLACK); else oled.drawCircle(122, 5, 3, SSD1306_BLACK);
  oled.setTextColor(SSD1306_WHITE);
}

static void drawFooter(uint8_t n, uint8_t current) {
  int x0 = 64 - (n * 6) / 2;
  for (uint8_t i = 0; i < n; i++) {
    if (i == current) oled.fillCircle(x0 + i * 6 + 2, 61, 2, SSD1306_WHITE);
    else oled.drawPixel(x0 + i * 6 + 2, 61, SSD1306_WHITE);
  }
}

static void bigValue(int x, int y, const String& v, const char* unit) {
  oled.setTextSize(2); oled.setCursor(x, y); oled.print(v);
  oled.setTextSize(1); oled.setCursor(x + v.length() * 12 + 2, y + 7); oled.print(unit);
}

static void pageStatus() {
  drawHeader("SENTINEL-X");
  oled.drawBitmap(4, 16, ICON_SHIELD, 16, 16, SSD1306_WHITE);
  oled.setTextSize(2); oled.setCursor(26, 16); oled.print("SX-G1-01");
  oled.setTextSize(1);
  oled.setCursor(4, 36); oled.print(WiFi.isConnected() ? "IP " + WiFi.localIP().toString() : String("WiFi: connexion..."));
  oled.setCursor(4, 47);
  oled.print(mqtt.connected() ? (TLS_ENABLED ? "MQTT TLS OK" : "MQTT OK") : "MQTT: OFF");
  oled.setCursor(86, 47); oled.print("fw "); oled.print(FW_VERSION);
}

static void pageClimate() {
  drawHeader("CLIMAT");
  oled.drawBitmap(2, 15, ICON_THERMO, 16, 16, SSD1306_WHITE);
  oled.drawBitmap(77, 15, ICON_DROP, 16, 16, SSD1306_WHITE);
  if (dhtValid()) {
    bigValue(18, 16, String(rd.temp, 1), "C");
    bigValue(95, 16, String((int)rd.hum), "%");
  } else {
    oled.setTextSize(1); oled.setCursor(18, 20); oled.print("--.-"); oled.setCursor(95, 20); oled.print("--");
  }
  // courbe de température des 4 dernières minutes
  const int gx = 2, gy = 36, gw = 124, gh = 18;
  oled.drawFastHLine(gx, gy + gh, gw, SSD1306_WHITE);
  if (tempHistN >= 2) {
    float lo = 1e9, hi = -1e9;
    for (uint8_t i = 0; i < tempHistN; i++) { float v = tempHist[i]; if (v < lo) lo = v; if (v > hi) hi = v; }
    if (hi - lo < 1.0f) { float c = (hi + lo) / 2; lo = c - 0.5f; hi = c + 0.5f; }
    int px = -1, py = -1;
    for (uint8_t i = 0; i < tempHistN; i++) {
      uint8_t idx = (tempHistHead + TEMP_HIST_N - tempHistN + i) % TEMP_HIST_N;
      int x = gx + (int)((long)i * (gw - 1) / (TEMP_HIST_N - 1));
      int y = gy + gh - 1 - (int)((tempHist[idx] - lo) / (hi - lo) * (gh - 2));
      if (px >= 0) oled.drawLine(px, py, x, y, SSD1306_WHITE);
      px = x; py = y;
    }
    oled.fillCircle(px, py, 2, SSD1306_WHITE);
  }
}

static void pageGas() {
  drawHeader("GAZ / FUMEE");
  oled.drawBitmap(2, 15, ICON_FLAME, 16, 16, SSD1306_WHITE);
  bigValue(22, 16, String(rd.gasRaw), "raw");
  oled.setTextSize(1); oled.setCursor(2, 36);
  if (gasBase < 0) {
    oled.print("chauffe du capteur...");
  } else {
    int delta = (int)(rd.gasRaw - gasBase);
    oled.print("base "); oled.print((int)gasBase); oled.print("  ecart "); if (delta >= 0) oled.print("+"); oled.print(delta);
    // jauge : 0 .. +GAS_DELTA_CRIT, repères attention / critique
    const int bx = 2, by = 47, bw = 124, bh = 8;
    oled.drawRect(bx, by, bw, bh, SSD1306_WHITE);
    float frac = delta <= 0 ? 0 : (delta >= GAS_DELTA_CRIT ? 1.0f : (float)delta / GAS_DELTA_CRIT);
    if (frac > 0) oled.fillRect(bx + 1, by + 1, (int)((bw - 2) * frac), bh - 2, SSD1306_WHITE);
    int xw = bx + (int)((bw - 2) * (float)GAS_DELTA_WARN / GAS_DELTA_CRIT);
    oled.drawFastVLine(xw, by - 2, bh + 4, SSD1306_WHITE);
    oled.drawFastVLine(bx + bw - 1, by - 2, bh + 4, SSD1306_WHITE);
  }
}

static void pageSecurity() {
  drawHeader("SECURITE");
  oled.drawBitmap(4, 15, ICON_PERSON, 16, 16, SSD1306_WHITE);
  oled.setTextSize(1);
  oled.setCursor(26, 16); oled.print("Mouvement PIR");
  oled.setCursor(26, 25); oled.print(!rd.pirSeenLow ? "> non branche" : rd.motion ? "> PRESENCE" : "> zone libre");
  oled.drawBitmap(4, 36, ICON_CAMERA, 16, 16, SSD1306_WHITE);
  oled.setCursor(26, 37); oled.print("Camera IA");
  oled.setCursor(26, 46); oled.print(al.camera ? "> INTRUSION" : "> zone libre");
  oled.setCursor(96, 46); oled.print(melody.playing ? "SON" : "   ");
}

static void pageAlert() {
  drawHeader("!! ALERTE !!");
  oled.drawBitmap(4, 18, ICON_WARN, 16, 16, SSD1306_WHITE);
  oled.setTextSize(2); oled.setCursor(26, 18);
  if (al.camera && al.motion) oled.print("CAM+PIR");
  else if (al.camera) oled.print("CAMERA");
  else if (al.motion) oled.print("PIR");
  else if (al.gas) oled.print(al.gasCrit ? "GAZ !!" : "GAZ");
  else if (al.temp) oled.print("TEMP");
  else if (al.hum) oled.print("HUMID.");
  else oled.print("CAPTEUR");
  oled.setTextSize(1); oled.setCursor(4, 40);
  if (al.camera) oled.print("Intrus vu par camera");
  else if (al.motion) oled.print("Mouvement detecte");
  else if (al.gas) { oled.print("Gaz : "); oled.print(rd.gasRaw); oled.print(" (+"); oled.print((int)(rd.gasRaw - gasBase)); oled.print(")"); }
  else if (al.temp) { oled.print("Temperature "); oled.print(rd.temp, 1); oled.print(" C"); }
  else if (al.hum) { oled.print("Humidite "); oled.print((int)rd.hum); oled.print(" %"); }
  else oled.print("DHT22 sans reponse");
  oled.setCursor(4, 51); oled.print(melody.playing ? "Sirene active" : "Sirene terminee");
}

static void drawOled() {
  if (!oledOk) return;
  unsigned long now = millis();
  if (now - oledPageSince >= OLED_PAGE_MS) { oledPage = (oledPage + 1) % 4; oledPageSince = now; }
  oled.clearDisplay();
  oled.setTextColor(SSD1306_WHITE);
  if (al.any()) {
    pageAlert();
    bool inv = (now / 500) % 2 == 0;             // clignotement par inversion matérielle
    if (inv != oledInverted) { oled.invertDisplay(inv); oledInverted = inv; }
  } else {
    if (oledInverted) { oled.invertDisplay(false); oledInverted = false; }
    switch (oledPage) {
      case 0: pageStatus(); break;
      case 1: pageClimate(); break;
      case 2: pageGas(); break;
      default: pageSecurity(); break;
    }
    drawFooter(4, oledPage);
  }
  oled.display();
}

// ----------------------------------------------------------------------------- actionneurs
static void tickActuators(unsigned long now) {
  bool online = WiFi.isConnected() && mqtt.connected();
  Actuator* acts[] = {&buzzer, &ledR, &ledG};
  for (Actuator* a : acts) {
    if (a->manual && a->until && now >= a->until) {   // fin de pulse / blink / on temporisé
      a->manual = false; a->blink = false; a->level = false;
    }
    if (a->manual && a->blink && now - a->lastToggle >= BLINK_PERIOD_MS) {
      a->level = !a->level; a->lastToggle = now;
    }
  }
  if (!buzzer.manual) buzzer.level = now < buzzerAutoUntil;
  if (!ledR.manual) ledR.level = al.any() || !online;
  if (!ledG.manual) ledG.level = online && !al.any();
  if (buzzer.level && !melody.playing) melodyStart(now);     // alarme : mélodie (en boucle tant que demandée)
  if (!buzzer.level && melody.playing) melodyStop();
  melodyTick(now);
  digitalWrite(ledR.pin, ledR.level ? HIGH : LOW);
  digitalWrite(ledG.pin, ledG.level ? HIGH : LOW);
}

// "off" rend la main au mode automatique (et coupe la sirène auto pour le buzzer).
// "on" sans durée reste manuel jusqu'à la prochaine commande.
static void applyCommand(Actuator& a, const char* action, unsigned long duration, unsigned long now) {
  if (!strcmp(action, "off")) {
    a.manual = false; a.blink = false; a.level = false; a.until = 0;
    if (&a == &buzzer) buzzerAutoUntil = 0;
    return;
  }
  a.manual = true;
  a.lastToggle = now;
  a.level = true;
  a.blink = !strcmp(action, "blink");
  if (!strcmp(action, "pulse"))  a.until = now + (duration ? duration : (&a == &buzzer ? BUZZER_AUTO_MS : 1000));
  else if (a.blink)              a.until = now + (duration ? duration : 3000);
  else                           a.until = duration ? now + duration : 0;   // "on"
}

static void handleCommand(const JsonDocument& doc) {
  const char* actuator = doc["actuator"] | "";
  const char* action   = doc["action"]   | "";
  unsigned long duration = doc["duration_ms"] | 0UL;
  unsigned long now = millis();
  if      (!strcmp(actuator, "buzzer"))    applyCommand(buzzer, action, duration, now);
  else if (!strcmp(actuator, "led_red"))   applyCommand(ledR, action, duration, now);
  else if (!strcmp(actuator, "led_green")) applyCommand(ledG, action, duration, now);
  else if (!strcmp(actuator, "led")) { applyCommand(ledR, action, duration, now); applyCommand(ledG, action, duration, now); }
  else if (!strcmp(actuator, "camera")) {          // intrusion détectée par la vision IA : écran, LED rouge, bip
    bool on = !strcmp(action, "on");
    if (on && !al.camera) buzzerAutoUntil = now + BUZZER_AUTO_MS;
    al.camera = on;
  }
  else { Serial.printf("[cmd] actionneur inconnu: %s\n", actuator); return; }
  Serial.printf("[cmd] %s %s %lu ms (%s)\n", actuator, action, duration, doc["cmd_id"] | "-");
}

// ----------------------------------------------------------------------------- MQTT
static void publishJson(const char* suffix, JsonDocument& doc, bool retain = false) {
  char buf[512];
  size_t n = serializeJson(doc, buf, sizeof(buf));
  if (!mqtt.publish(topic(suffix).c_str(), reinterpret_cast<const uint8_t*>(buf), n, retain))
    Serial.printf("[mqtt] publication %s echouee (%u octets)\n", suffix, (unsigned)n);
}

static void publishStatus(bool online) {
  JsonDocument doc;
  doc["device_id"] = DEVICE_ID;
  doc["online"] = online;
  if (online) { doc["ip"] = WiFi.localIP().toString(); doc["fw"] = FW_VERSION; }
  publishJson("status", doc, true);
}

#ifndef BENCH_NO_WIFI
static void publishTelemetry() {
  JsonDocument doc;
  doc["device_id"] = DEVICE_ID;
  doc["uptime_ms"] = millis();
  if (dhtValid()) {
    doc["temperature"] = roundf(rd.temp * 10) / 10;
    doc["humidity"]    = roundf(rd.hum * 10) / 10;
  }
  doc["gas_raw"]   = rd.gasRaw;
  doc["gas_ppm"]   = roundf(rd.gasPpm * 10) / 10;
  doc["motion"]    = rd.motion;
  doc["rssi"]      = WiFi.RSSI();
  doc["heap_free"] = ESP.getFreeHeap();
  publishJson("telemetry", doc);
}
#endif

static void publishAlert(const char* type, bool on, float value, const char* severity) {
  JsonDocument doc;
  doc["device_id"] = DEVICE_ID;
  doc["uptime_ms"] = millis();
  doc["type"]      = type;
  doc["state"]     = on ? "on" : "off";
  doc["value"]     = value;
  doc["severity"]  = severity;
  publishJson("alerts", doc);
  Serial.printf("[alert] %s %s (%.1f) %s\n", type, on ? "ON" : "OFF", value, severity);
  // Sirène sur gaz, température, PIR (et caméra via la commande) ; pas sur l'humidité (souffle, main = faux positifs) ni les pannes capteur
  if (on && strcmp(type, "sensor_fault") != 0 && strcmp(type, "humidity") != 0)
    buzzerAutoUntil = millis() + BUZZER_AUTO_MS;
}

static void onMqttMessage(char* t, uint8_t* payload, unsigned int len) {
  JsonDocument doc;
  DeserializationError err = deserializeJson(doc, payload, len);
  if (err) { Serial.printf("[mqtt] JSON invalide sur %s : %s\n", t, err.c_str()); return; }
  if (topic("cmd") == t) handleCommand(doc);
}

#if TLS_ENABLED && defined(MQTT_CA_CERT)
static void syncTime() {
  configTime(0, 0, "pool.ntp.org", "time.nist.gov");
  Serial.print("[time] NTP");
  unsigned long t0 = millis();
  while (time(nullptr) < 1700000000UL && millis() - t0 < 5000) { delay(200); Serial.print("."); }
  if (time(nullptr) < 1700000000UL) {
    timeval tv = { (time_t)BUILD_EPOCH, 0 };   // réseau isolé : date de compilation
    settimeofday(&tv, nullptr);
    Serial.println(" absent, date de compilation utilisee");
  } else {
    Serial.println(" OK");
  }
}
#endif

static bool mqttConnect() {
  String willTopic = topic("status");
  char will[96];
  snprintf(will, sizeof(will), "{\"device_id\":\"%s\",\"online\":false}", DEVICE_ID);
  Serial.printf("[mqtt] connexion %s:%d%s... ", MQTT_HOST, MQTT_PORT, TLS_ENABLED ? " (TLS)" : "");
  bool ok = mqtt.connect(DEVICE_ID, MQTT_USER, MQTT_PASS, willTopic.c_str(), 1, true, will);
  if (!ok) {
    Serial.printf("echec rc=%d", mqtt.state());
#if TLS_ENABLED
    char sslErr[96];
    int code = net.getLastSSLError(sslErr, sizeof(sslErr));
    if (code) Serial.printf(" ssl=%d %s", code, sslErr);
#endif
    Serial.printf(" (heap %u)\n", ESP.getFreeHeap());
    return false;
  }
  Serial.println("OK");
  Serial.printf("[oled] %s | heap %u\n", oledOk ? "detecte a 0x3C" : "ABSENT (verifier SDA=D2 SCL=D1 3V G)", ESP.getFreeHeap());
  mqtt.subscribe(topic("cmd").c_str(), 1);
  publishStatus(true);
  return true;
}

// ----------------------------------------------------------------------------- capteurs
static float mq2Rs(int raw) {
  float v = raw / 1023.0f * 3.3f * MQ2_DIVIDER_RATIO;   // tension en sortie AO du capteur
  if (v < 0.01f) v = 0.01f;
  return MQ2_RL_KOHM * (MQ2_VCC - v) / v;                // Rs en kΩ
}
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
void loop() {
  unsigned long now = millis();

  if (WiFi.isConnected()) {
    if (!mqtt.connected()) {
      if (now - tMqttRetry >= MQTT_RETRY_MS) { tMqttRetry = now; mqttConnect(); }
    } else {
      mqtt.loop();
    }
  }

  if (now - tSensor >= SENSOR_PERIOD_MS) {
    tSensor = now;
    readSensors(now);
    evalAlerts();
  }
  if (now - tTelemetry >= TELEMETRY_PERIOD_MS) {
    tTelemetry = now;
#ifdef BENCH_NO_WIFI
    Serial.printf("[banc] T=%s H=%s gaz=%d pir=%d heap=%u\n",
                  dhtValid() ? String(rd.temp, 1).c_str() : "--", dhtValid() ? String(rd.hum, 0).c_str() : "--",
                  rd.gasRaw, rd.motion ? 1 : 0, ESP.getFreeHeap());
#else
    if (mqtt.connected()) publishTelemetry();
#endif
  }
  if (!oledOk && now - oledProbeAt >= 10000) {        // écran branché après coup, ou fil remis en place
    oledProbeAt = now;
    if ((oledOk = oledProbe())) Serial.printf("[oled] detecte a 0x%02X (branchement tardif)\n", oledAddr);
  }
  if (now - tOled >= OLED_PERIOD_MS) {
    tOled = now;
    drawOled();
  }
  tickActuators(now);
  yield();
}

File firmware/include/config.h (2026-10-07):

#pragma once
// Configuration matérielle et fonctionnelle du boîtier. Les secrets sont dans secrets.h.

// ---- Identité (docs/CONTRAT_DONNEES.md §1) ----
#define DEVICE_ID     "SX-G1-01"
#define FW_VERSION    "0.1.0"
#define TOPIC_PREFIX  "sentinel/g1"

// ---- Broches (docs/CABLAGE.md §1) ----
#define PIN_OLED_SCL   D1   // GPIO5
#define PIN_OLED_SDA   D2   // GPIO4
#define PIN_DHT        D5   // GPIO14
#define DHT_TYPE       DHT22 // DHT11 si le capteur est le modèle bleu
#define PIN_PIR        D6   // GPIO12
#define PIN_BUZZER     D7   // GPIO13 (via transistor NPN)
#define PIN_LED_RED    D0   // GPIO16
#define PIN_LED_GREEN  D8   // GPIO15 (doit être bas au boot : LED vers masse = OK)
#define PIN_GAS        A0   // ADC via pont diviseur 10k/20k

// ---- Wi-Fi ----
// Puissance d'émission en dBm (max 20.5). 17 suffit largement sur une table et réduit le
// courant de pointe, utile quand l'ESP est alimenté par un port USB ou un hub faiblard.
#define WIFI_TX_DBM  17.0f

// ---- Cadences (ms) ----
#define SENSOR_PERIOD_MS     2000   // DHT22 : 2 s minimum entre deux lectures
#define TELEMETRY_PERIOD_MS  5000   // contrat §2
#define OLED_PERIOD_MS        500
#define MQTT_RETRY_MS        5000
#define MQ2_WARMUP_MS      180000   // chauffe du MQ-2 : pas d'alerte gaz ni de ppm avant 3 min

// ---- Seuils locaux "réflexe" (contrat §6) ----
#define TEMP_WARN  35.0f
#define TEMP_CRIT  45.0f
#define HUM_WARN   80.0f
#define HUM_CRIT   90.0f
// Gaz : seuils RELATIFS à la ligne de base mesurée après la chauffe (robuste au 3,3 V / 5 V et à la dérive)
#define GAS_DELTA_WARN   80
#define GAS_DELTA_CRIT  200
#define HYST_TEMP   2.0f
#define HYST_HUM    3.0f
#define HYST_GAS   30

// ---- MQ-2 : estimation ppm (courbe GPL de la datasheet, indicative) ----
#define MQ2_DIVIDER_RATIO  1.0f    // montage minimal : MQ-2 en 3,3 V, AO direct sur A0 (1.5f avec diviseur 10k/20k)
#define MQ2_VCC            3.3f    // 5.0f si le MQ-2 est alimenté en 5 V
#define MQ2_RL_KOHM        5.0f    // résistance de charge du module (1k sur certains modules)
#define MQ2_CLEAN_AIR_RATIO 9.83f  // Rs/R0 en air propre (datasheet)

// ---- Actionneurs ----
// Buzzer PASSIF (module 3 broches, signal sur D7) : le firmware joue une mélodie par PWM (tone()).
// BUZZER_AUTO_MS = durée de la sirène automatique sur alerte (≈ la mélodie à 100 %).
#define BUZZER_AUTO_MS  7372
#define MELODY_SPEED_PCT 100   // 100 = tempo du jeu ; 150 = une fois et demie plus lent
#define BLINK_PERIOD_MS  200

// ---- OLED ----
#define OLED_ADDR  0x3C
#define OLED_W     128
#define OLED_H     64

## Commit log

2026-10-06 feat(firmware): ESP8266 DHT22/MQ-2/PIR, OLED, MQTTS, alertes à seuils, commandes buzzer/LED/caméra, mode banc
    [config.h, main.cpp]
2026-10-06 docs: contrat de données, architecture, câblage, boîtier, base de données, plaque de gravure laser
2026-10-06 feat(firmware): buzzer passif 3 broches, lecteur de mélodie non bloquant (Hava Nagila) sur alarme, bouton Alarme du dashboard
    [config.h, main.cpp]
2026-10-06 feat(firmware): alarme sur le riff de Doom E1M1, transposé dans les aigus pour le volume du piézo
2026-10-06 feat(firmware): retour au thème de Mario pour l'alarme, octave 5-6
2026-10-06 fix(firmware): riff Doom E1M1 corrigé (si bémol, montée chromatique si-do)
    [main.cpp]
2026-10-06 feat(ai): choix interactif de la caméra au lancement de vision.py
2026-10-06 feat(firmware): riff Doom E1M1 extrait du lump D_E1M1 de doom1.wad (piste guitare, durées réelles)
2026-10-06 fix(firmware): riff Doom pris sur le canal 1 du MUS (8 mesures, 10,7 s)
    [config.h, main.cpp]
2026-10-06 feat(fablab): boîtier 3D paramétrique CadQuery (base, couvercle, gabarit) exporté en STEP/STL, vue CAO dans le dossier
    [base.step, base.stl, couvercle.step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]
2026-10-06 feat(firmware): interface OLED en pages graphiques (état, climat avec courbe, gaz avec jauge, sécurité) défilant toutes les 7 s, page d'alerte clignotante
2026-10-06 feat(ai): personnes autorisées par reconnaissance faciale (YuNet + SFace), enrôlement, délai de grâce avant intrusion
2026-10-06 fix(ai): intrusion immédiate sauf visage reconnu (délai de grâce à 0 par défaut)
2026-10-06 fix(ai): décision d'intrusion par personne (visage reconnu dans la silhouette), un inconnu déclenche même à côté d'un autorisé
2026-10-06 fix(ai): confirmation de l'intrus sur 3 images consécutives
2026-10-06 fix(firmware): PIR débranché (broche flottante) ne déclenche plus, validation après un premier niveau bas
    [main.cpp]
2026-10-07 fix(firmware): détection de l'OLED aux adresses 0x3C/0x3D, nouvel essai toutes les 10 s si absent
    [main.cpp]
2026-10-07 feat(firmware): sirène sur toutes les alertes capteurs (gaz, température, humidité) dès le niveau attention
2026-10-07 fix(firmware): pas de sirène sur les alertes d'humidité (faux positifs au souffle)
    [main.cpp]
2026-10-07 feat(firmware): sonnerie Skype transcrite de l'enregistrement original
2026-10-08 feat(infra): moniteur d'attaques en direct pour la journee pentest
    Surligne les connexions reseau non reconnues (vraie IP via lsof, contourne le
    masquage Docker), les echecs d'authentification HTTP (401/403) et MQTT, et les
    scans de chemins sensibles. Lecture seule. Mac/ESP/conteneurs ignores.
2026-10-08 docs: dossier et archi a jour (reseau hotspot, moniteur d'attaques) + diapo securite oral
    - Reseau: repli hotspot partage documente, epinglage par empreinte independant de l'IP
    - Securite: ajout de la detection live (watch-attacks.sh) matrice + surveillance
    - ARCHITECTURE.md: validation coachs, ports 8010, empreinte vs CA
    - Nouvelle diapo PowerPoint 'Securite de la liaison' pour le passage a l'oral
2026-10-08 docs: script de soutenance (6 intervenants, chrono 10 min) + dossier PDF regenere
    Script oral reparti par personne sur le chrono impose (intro, teaser, demo live,
    pitch archi, pitch securite, Q&A). Dossier PDF reconstruit avec les sections a
    jour (reseau hotspot, moniteur d'attaques), 17 pages, rendu via puppeteer-core.
2026-10-08 docs: support de soutenance Workshop2026-M1-G1-Pres.pptx (9 diapos) + diapo securite alignee
    Deck cale sur docs/SCRIPT_ORAL.md : titre, menace, teaser, boitier, demo live,
    IA, architecture, securite, conclusion. Notes d'orateur par diapo. Mise en page
    verifiee diapo par diapo (rendu de controle avec polices plus larges), TLS
    formule en 1.2 et plus (BearSSL sur ESP8266).
2026-10-09 docs(readme): note sur le repli hotspot pour la demo
2026-10-09 docs: noms des six membres du groupe (dossier, poster, README), PDF regenere
2026-10-09 docs(dossier): version 1.1 du 9 octobre sur la couverture

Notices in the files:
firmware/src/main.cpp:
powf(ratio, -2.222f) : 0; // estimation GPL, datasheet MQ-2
